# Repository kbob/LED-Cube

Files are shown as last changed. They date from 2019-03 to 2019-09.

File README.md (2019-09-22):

# LED Cube

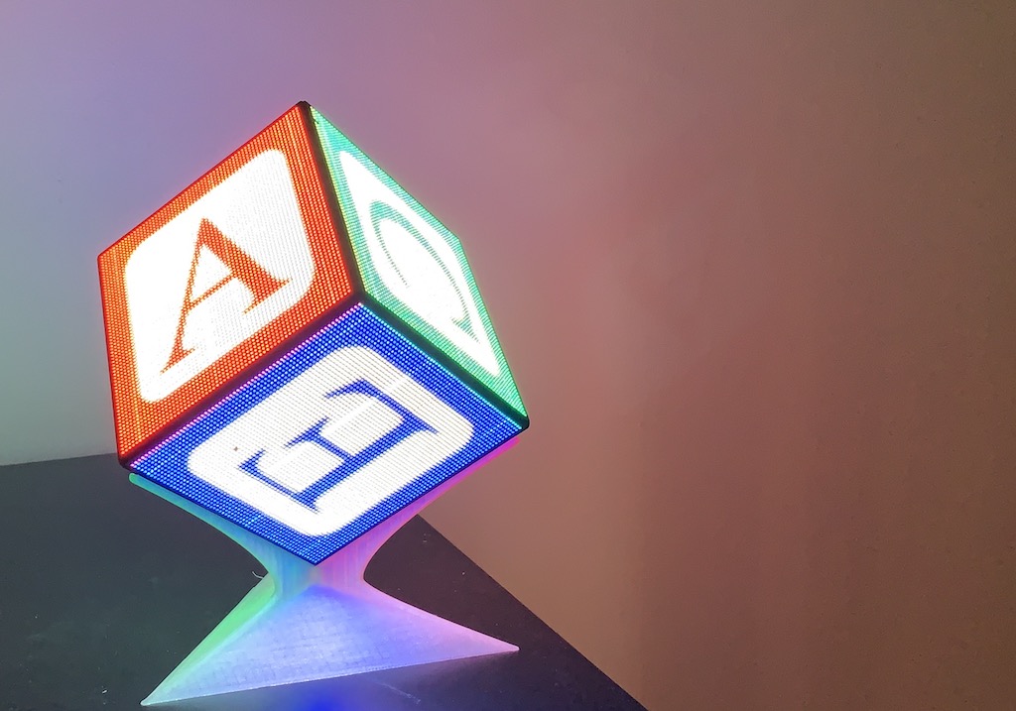
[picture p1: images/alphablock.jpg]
The cube on its stand.


A cube made of RGB LED panels.

I saw [Zaurak's and Polyfloyd's LED cubes](https://kbob.github.io/2019/08/23/led-cubes.html), and decided I wanted to make one too.  This one is smaller with denser LEDs.  (2mm pitch instead of 2.5mm)

# Overview

The cube's faces are six LED panels from Aliexpress.  Each panel has 64&times;64 RGB leds and is driven by the HUB75 protocol.

The chassis is a combination of 3D printed PLA, machine screws, and magnets.
The electronics can be installed and removed without tools.

The electronics consist of a Raspberry Pi connected via USB to an
[iCEBreaker FPGA](https://www.crowdsupply.com/1bitsquared/icebreaker-fpga)
dev board, HUB75 PMOD interface, and the panels.

Power is provided by an eight pack of 18650 batteries and a custom
power supply.  The power board also has an inertial measurement
unit (IMU), battery level monitoring, and soft power controls.

I also have two different display stands that prop the cube up on
one corner.  One stand disassembles for easy transport; the other, shown above,
is more stable and has a (bulky) carrying case.  All this is 3D printed.

# What's Here?

* **Mechanical/** CAD files, STL files, and parts lists.  The two
  display stands are here too.

* **Power Board/** KiCAD files and BOM for the custom power board.

* **Wiring/** Notes on the wiring harness.

* **Linux/** Notes on configuring Linux on the Raspberry Pi.

# What's Missing?

There are several different software options.  I outlined them in
[this 'blog post](https://kbob.github.io/2019-08-23/led-cubes.html).
None of them are in this repository.  I couldn't even begin
to write a comprehensive installation guide for them all.

The gateware is based on [tnt's excellent
ice40-playground](https://github.com/smunaut/ice40-playground).
But I have my own fork [here](https://github.com/kbob/ice40-playground).
My cube uses the `topic-cube` branch.  I haven't checked whether everything
in that branch has made it back upstream.

# What's Coming (I hope)?

## Raspberry Pi 4

My cube has a Raspberry Pi 3 Model A+.  (What a mouthful!)
Shortly after I built it, the Raspberry Pi foundation announced
the Raspberry Pi 4.  Its GPU is much better, and I really want to
get it into my cube.  But of course it's a different size;
I have to redesign part of the chassis to make it fit.

# Mesa OpenGL

I am using Broadcom's proprietary OpenGL.  I want to get the
open source Mesa GL running, but haven't figured out the magic
yet.  (It's complicated because I refuse to install an X11 server;
I only want offscreen rendering.)

# More LED Panels

**Update 2019-09-22:**  Good news!  1BitSquared now has [the correct
LED panels](https://1bitsquared.com/collections/embedded-hardware/products/led-panel)
in stock.  Get the ICN2037 variant.

The Aliexpress vendors do not ship a single version of the HUB75
panels.  Instead, you get whatever vendors happen to be available
surplus.  Each version has different driver chips, timing requirements,
mechanical layout, even power voltage requirements.  So today
the panels on the cube are irreplaceable.  If one dies, I'll
have no cube.

~~Esden is working on getting a reliable source for LED panels.
Follow him on twitter ([@esden](https://twitter.com/esden))
to stay up to date.~~

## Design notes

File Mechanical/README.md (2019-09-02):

# LED Cube Mechanicals

This directory holds the mechanical parts of the cube
and its accessories.  It is organized into subdirectories.

* **Cube/** The cube.

 

* **Interlocking Stand/** Display stand made of three
interlocking pieces.  Breaks down for easy transport.

 

* **Display Stand/** Single-piece display stand.  Sturdier
than the interlocking stand but bulkier.

 

* **Display Stand/Travel Case/** a travel case for the
single-piece display stand.

 

Each subdirectory should have a README, a BOM, some Fusion 360 files, some STL files, and a picture or two.

## Versions

Each Fusion 360 file has a version number appended.
Fusion 360 exports do not include version history,
so earlier versions are not available, in general.

Some Fusion 360 files have both a generation and
a version.  Sometimes I just gave up on a design and started over.
When I did, I added a generation number.  *e.g.*, `Pi Connector Cover 4 v3.f3d`.
That's version 3 of the 4th try to design a connector cover.

Each STL file has a version number appended.  That
corresponds to the Fusion 360 version where that
body was last changed.  So the STL versions will
generally be less than the F360 version.  Version
64 of the cube uses v35 of the lid, for example.

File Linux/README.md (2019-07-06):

# Linux Configuration

The Raspberry Pi inside the cube runs Linux.  There are
a few necessary steps to configure it.  This file is
a checklist of things to set up.

## Make Image.

Get a Raspbian-Lite image from
[raspberrypi.org](https://www.raspberrypi.org/downloads/).
Burn it to a Micro SD card.

## Set up soft power.

Before putting the card into the Raspberry Pi, append this to /boot/config.txt.

    # BEGIN kbob 2019-03-25 configure soft power GPIO
    dtoverlay=gpio-shutdown,gpio_pin=17,active_low=1,gpio_pull=up
    dtoverlay=gpio-poweroff,gpiopin=4,active_low=1,export=1
    # END kbob 2019-03-25

## Configure Wi-Fi

Before putting the card into the Raspberry Pi, create the file
`/boot/wpa_supplicant.conf`.

    country=us
    update_config=1
    ctrl_interface=/run/wpa_supplicant

    network={
      scan_ssid=1
      ssid="(your network SSID)"
      psk="(your network password)"
    }

Duplicate the `network={...}` stanza if you have several Wi-Fi networks.

## Enable ssh.

Before putting the card into the Raspberry Pi, create an empty file
`/boot/ssh`.

## Boot Raspberry Pi.

The Pi should boot and bring up Wi-Fi.  Use a network scanner to find
it and log in.

## Change the password.

Immediately run `sudo raspi-config` and change the default user's
login password.

## Run `raspi-config`

Use `sudo raspi-config` to change the hostname, locale and timezone and
enable I&sup2;C.  Also select the "legacy" GL driver.

GL driver is under Advanced Options.

## Expand swap space

Building the FPGA tools requires 4 GB of swap.  Edit
`/etc/dphys-swapfile` and set these.

    CONF_SWAPSIZE=4096
    CONF_MAXSWAP=4096

N.B., this is not a sane swap configuration.  But building the FPGA toolchain
on a Raspberry Pi is not a sane thing to do.

Reboot to enable the new swap space.

## Enable Bonjour ssh service.

Create `/etc/avahi/services/ssh.service`.

    $ sudo cp /usr/share/doc/avahi-daemon/ssh.service /etc/avahi/services/

## Update and install packages

    $ sudo apt-get update
    $ sudo apt-get dist-upgrade

These packages are needed for the FPGA tools.

    $ sudo apt-get install git mercurial build-essential bison clang cmake \
                           flex gawk graphviz xdot libboost-all-dev \
                           libeigen3-dev libffi-dev libftdi-dev libgmp3-dev \
                           libmpfr-dev libncurses5-dev libmpc-dev \
                           libreadline-dev zlib1g-dev pkg-config python \
                           python3 python3-dev tcl-dev autoconf gperf

## Summon the FPGA tools.

    $ git clone https://github.com/esden/summon-fpga-tools.git
    $ cd summon-fpga-tools
    $ ./summon-fpga-tools.sh CPUS=1 NEXTPNR_BUILD_GUI=off

This will run for several hours.  Good time to take a break.

# Apt History

Here is the raw history.  Some of these are probably not needed.

```text
history.log.1:Commandline: apt-get install raspi-config
history.log.1:Commandline: apt-get dist-upgrade
history.log.1:Commandline: apt-get install git
history.log.1:Commandline: apt-get install build-essential clang bison flex libreadline-dev gawk tcl-dev libffi-dev git mercurial graphviz xdot pkg-config python python3 libftdi-dev python3-dev libboost-all-dev cmake libeigen3-dev
history.log.1:Commandline: apt-get install autoconf
history.log.1:Commandline: apt-get install gperf
history.log.1:Commandline: apt-get install python3-pip
history.log.1:Commandline: apt-get install python3-ftdi1
history.log.1:Commandline: apt-get install emacs-nox
history.log.1:Commandline: apt-get install swig
history.log:Commandline: apt-get install python-virtualenv
history.log:Commandline: apt-get install mesa-utils
history.log:Commandline: apt-get install python-imaging
history.log:Commandline: apt-get purge mesa-utils
history.log:Commandline: apt-get install golang
history.log:Commandline: apt-get install libgl1-mesa-dev
history.log:Commandline: apt-get install libegl1-mesa-dev
history.log:Commandline: apt-get install ffmpeg
history.log:Commandline: apt-get install libgbm-dev
history.log:Commandline: apt-get install ltrace
history.log:Commandline: apt-get install stress
history.log:Commandline: apt-get install i2c-tools
history.log:Commandline: apt-get install libgles2-mesa-dev
history.log.1:Commandline: apt-get install python3-pygments
history.log.1:Commandline: apt-get install python-pygments
history.log.1:Commandline: apt-get install tig
history.log.1:Commandline: apt-get dist-upgrade
history.log.1:Commandline: apt-get install apt-rdepends
history.log.1:Commandline: apt autoremove
history.log.1:Commandline: apt-get install git libeigen3-dev cmake wiringpi libboost-all-dev libasound2-dev libprotobuf-dev protobuf-compiler
history.log:Commandline: apt-get install mesa-utils-extra
history.log:Commandline: apt-get install avahi-utils
history.log:Commandline: apt install vim
history.log:Commandline: apt-get install libegl1-mesa-drivers
history.log:Commandline: apt-get install netpbm
history.log:Commandline: apt-get install libnetpbm10-dev
history.log:Commandline: apt-get install valgrind
history.log:Commandline: apt-get install python3-pil
history.log:Commandline: apt-get install python3-numpy
```

(more to come...)

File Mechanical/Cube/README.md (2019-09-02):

# The Cube - Mechanical

This directory contains the CAD files (Fusion 360) and
STL files for the cube's 3D printed parts.  The BOM
lists those and  the other misc. parts needed to build
a cube.

There are no assembly instructions, sorry.

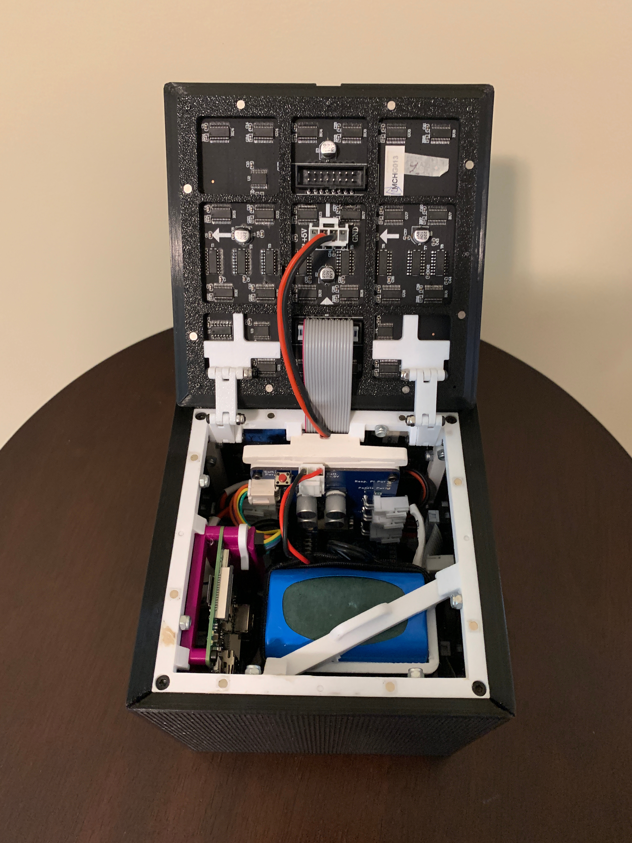
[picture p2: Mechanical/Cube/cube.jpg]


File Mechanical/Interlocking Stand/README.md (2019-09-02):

# Interlocking Display Stand

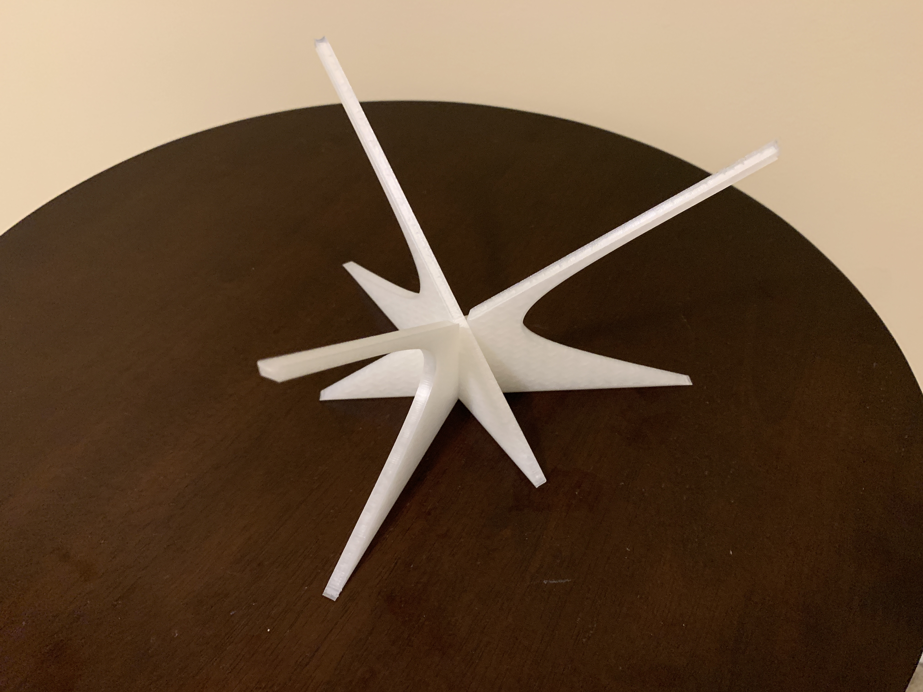
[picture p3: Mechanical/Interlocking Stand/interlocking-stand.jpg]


The interlocking display stand is 3D printed in three pieces.  They slide together to form the stand, and they
slide apart to lie flat for transport or storage.

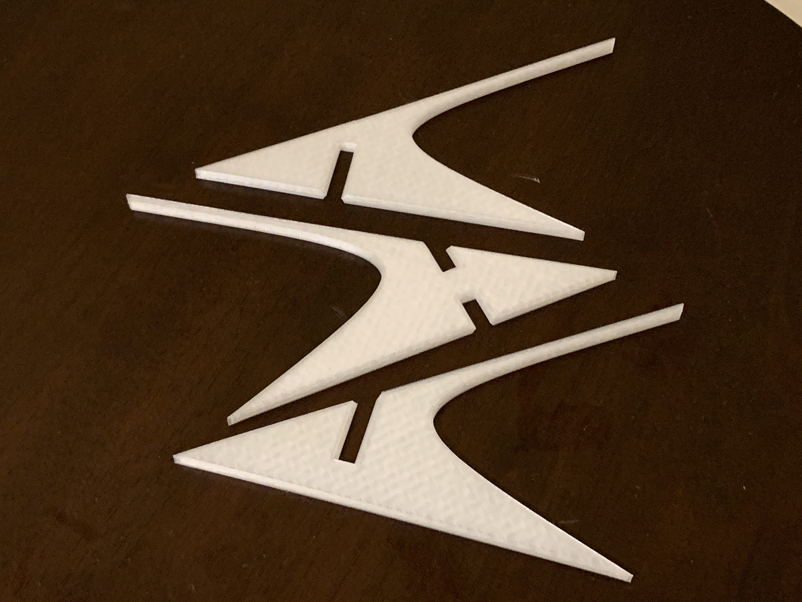
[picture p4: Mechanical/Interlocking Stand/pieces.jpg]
Pieces


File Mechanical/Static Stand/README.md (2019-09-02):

# Static Display Stand

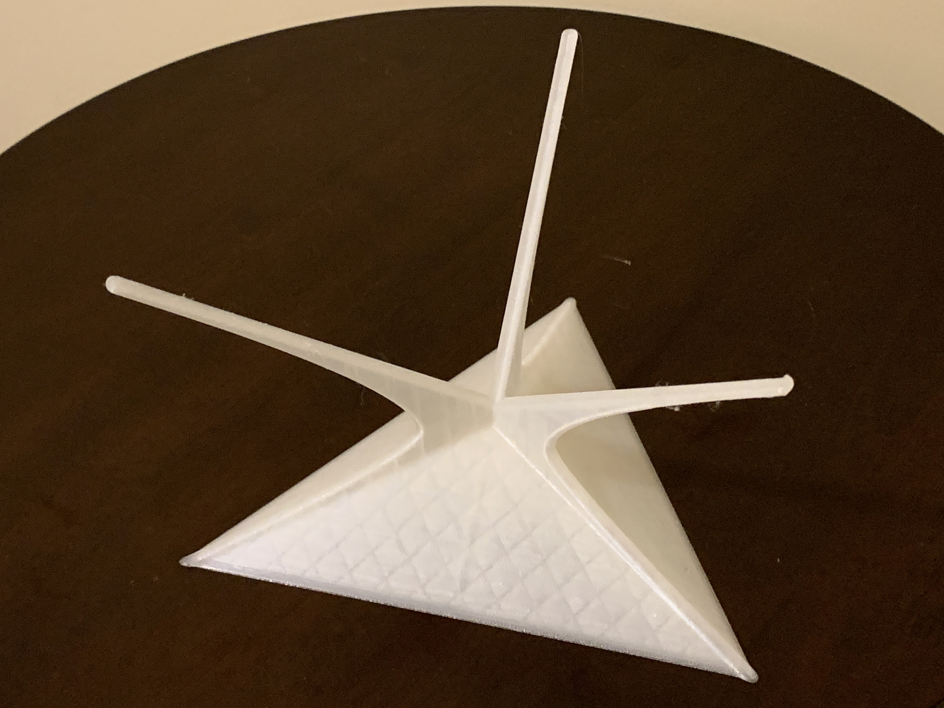
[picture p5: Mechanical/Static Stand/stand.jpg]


There is also a travel case in the `Travel Case/`
subdirectory.

The stand has a hole in the bottom that fits over
a short phonograph spindle.

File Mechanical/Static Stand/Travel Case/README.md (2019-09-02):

# Stand Travel Case

The travel case is 3D printed, held closed with rubber bands.
The stand is held in place by three plastic clips.

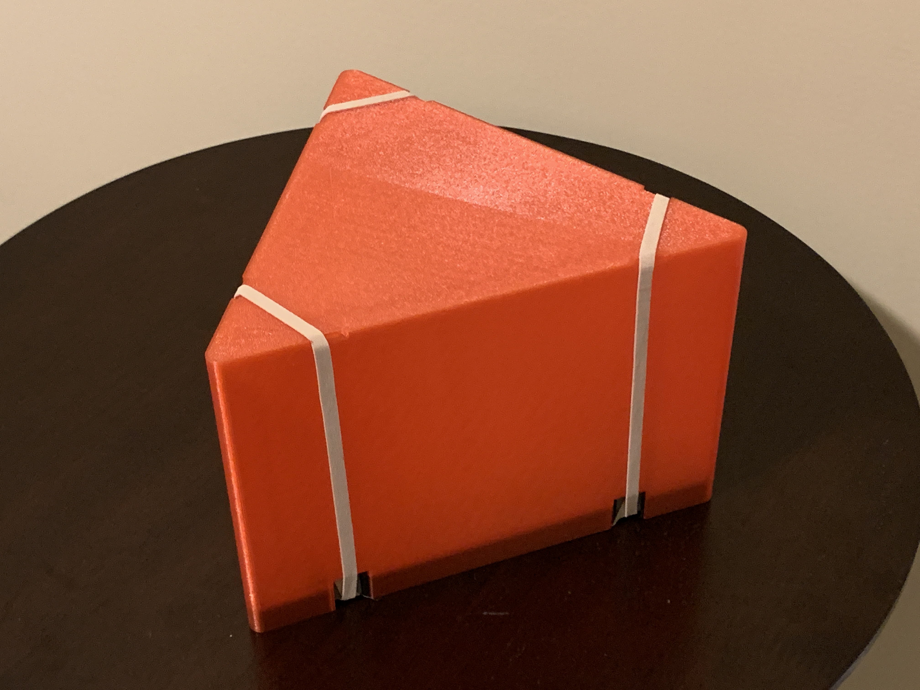
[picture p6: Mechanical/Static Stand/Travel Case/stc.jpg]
travel case


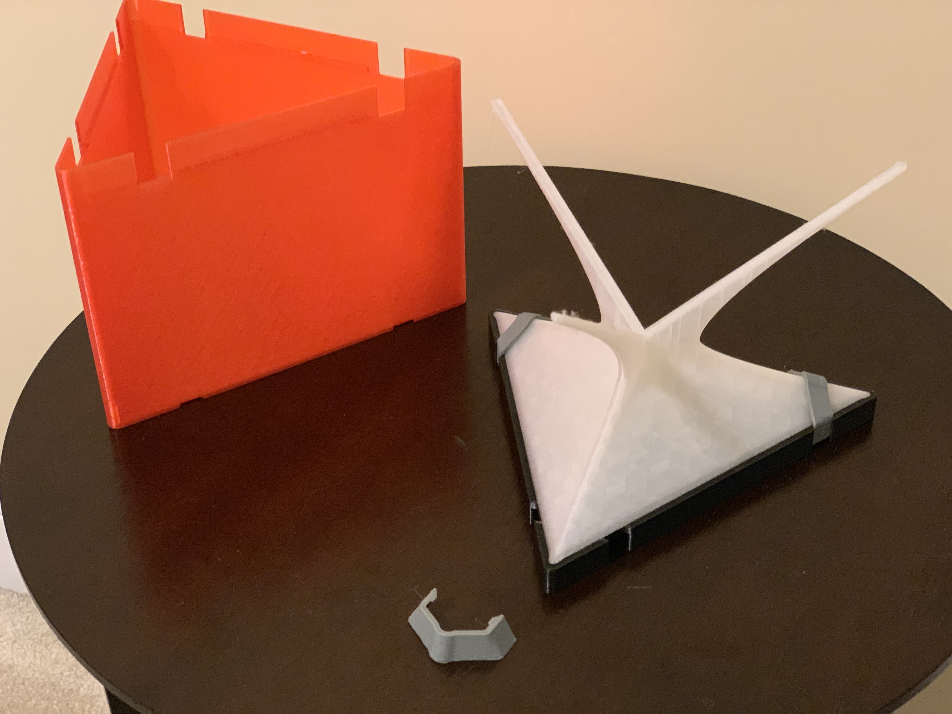
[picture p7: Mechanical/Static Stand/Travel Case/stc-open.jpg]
travel case open


It can optionally use another set of rubber bands for
redundant retention.

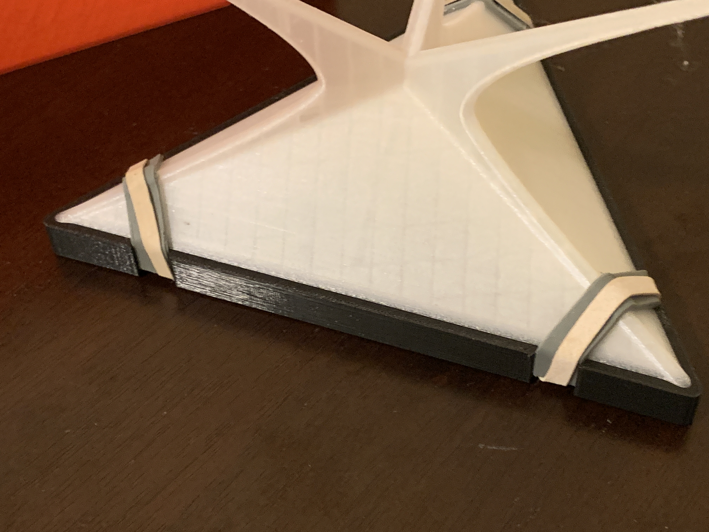
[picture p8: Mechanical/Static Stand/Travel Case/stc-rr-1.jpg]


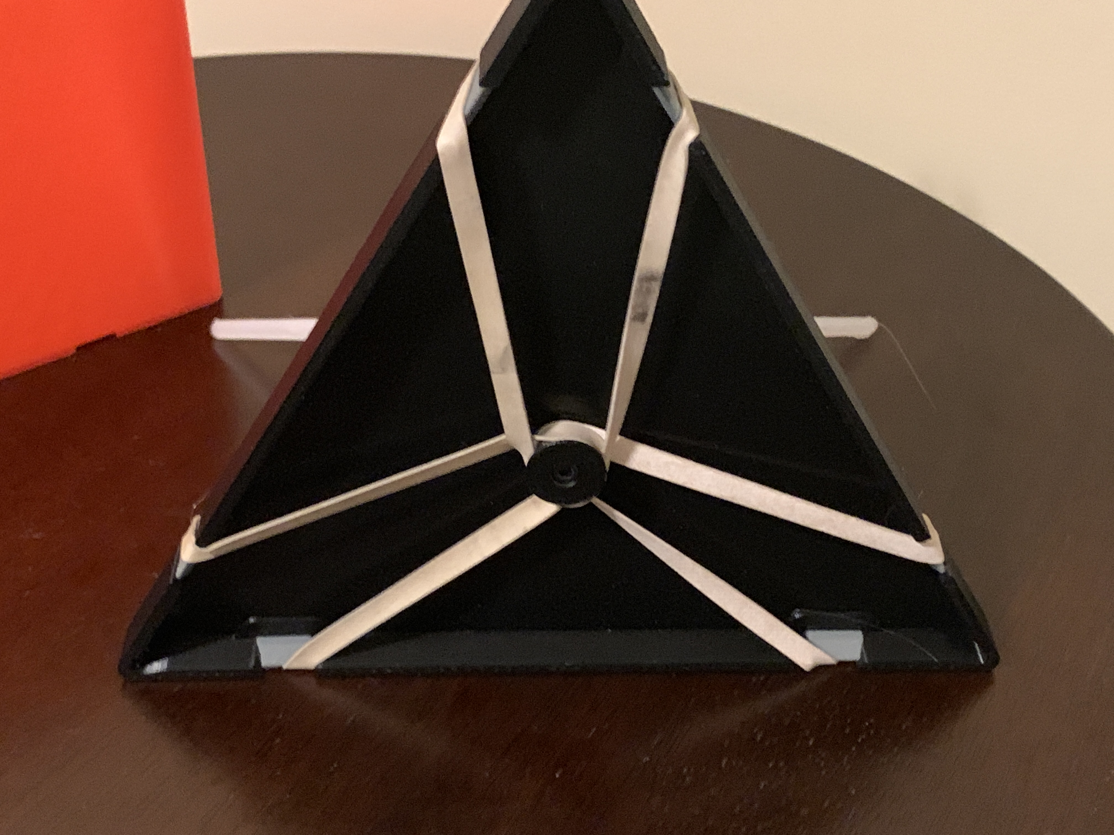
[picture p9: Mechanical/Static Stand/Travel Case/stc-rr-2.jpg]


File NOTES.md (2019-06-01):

# Raspberry Pi

## Configuration for soft power switch

In `/boot/config.txt`:
    # BEGIN kbob 2019-03-25 configure soft power GPIO
    dtoverlay=gpio-shutdown,gpio_pin=17,active_low=1,gpio_pull=up
    dtoverlay=gpio-poweroff,gpiopin=4,active_low=1,export=1
    # END kbob 2019-03-25

Some of those parameters are probably not needed.

# Power Board

## Power Board v0.3

### Capacitor Substitutions

Some of the caps I specified are not available.

Specifically, Digikey is out of these two.

    445-8047-1-ND     47uF 25V 1206
    490-1517-2-ND   0.22uF 50V 0603

And I incorrectly specified some 15V caps for components that are
expected to see 17V.

And Digikey does not carry NIC caps.

And it has been suggested that I use electrolytic caps instead
of some of these.

### Calculate LMZ14203 Parameters

#### Input Voltage

Nominal cell voltage is 3.7V.  Min is 3.3V; max is 4.2V.

Assume 4 cells.

```python
>>> vv = 3.3, 3.7, 4.2
>>> [4 * v for v in vv]
[13.2, 14.8, 16.8]
```

So nominal battery voltage is 14.8V, min and max are 13.2 and 16.8V.

#### Enable Divider

    Rent / Renb = (Vin_uvlo / 1.18V) - 1
    Rent / Renb + 1 = Vin_uvlo / 1.18V
    1.18V * (Rent / Renb + 1) = Vin_uvlo

    1.18V * (68K / 6.8K + 1) = 12.98V

So it will shut off when battery voltage drops below 12.98V.

#### FB voltage divider

Use R<sub>FBT</sub> = 5.90&ohm; and R<sub>FBB</sub> = 1.07&ohm;.

V<sub>0</sub> = 0.8V * (1 + R<sub>FBT</sub> / R<sub>FBB</sub>)
<br>
V<sub>0</sub> = 0.8V * (1 + 5.90 / 1.07)
<br>
V<sub>0</sub> = 5.21V

That's a healthy 5V. (-:

#### R<sub>ON</sub> Value

(See datasheet section 8.2.2.2.7.)

Minimum on time is 150ns.

R<sub>ON</sub> >= V<sub>IN(MAX)</sub> \* 150ns / (1.3 \* 10^-10)

R<sub>ON</sub> >= 16.8 * 150e-9 / 1.3e-10
       = 19384

T<sub>ON</sub> = (1.3 \* 10^-10 \* R<sub>ON</sub>) / V<sub>IN</sub>

WEBENCH uses 110K for R<sub>ON</sub>.  That gives T<sub>ON</sub> = 966nsec.
Is that good?  Is that bad?

## Calculate TPS53819A Parameters

All parameters are from WEBENCH.

## Power Board v0.2

### Polyfuses

    Bourns MF-MSMF250/16X-2
    as used on Raspberry Pi 3 Model B+

    LittelFuse 30R400UMR

    Better: LittelFuse NANOSMD400LR-C-2
    12V, 4A, 1206 SMT

### Capacitors

    Panasonic EEU-FC1C182S
    1800µF 16V 3000hours low ESR
    George I. recommended this one.

    Panasonic also makes some slightly shorter SMD caps.

    Panasonic EEU-FS1C511
    510uF, 16V, 6000 hours
    13mm high by 8mm diameter

    Digikey filtered list
    https://www.digikey.com/short/p347pv

### Connectors

   <!-- Solderable hole for power in
   2.54mm female socket for Raspberry Pi -->

   Molex SL connector for Raspberry Pi.
   070553-30001 receptacle      (right-angle, through hole, 2pos)
   50-57-9402   connector       (2pos, crimp)
   16-02-0103   socket contacts (22-24AWG, gold)
   mini-PV connector for Pi
   pins for mini-PV

  JST B2PS-VH for panel outputs.
  JST VHR-2N for cables
  JSR VHR-4N for LED panel end
  Plus crimp connectors.
  JST SVH-21T-P1.1

## Digi-Key order

    QTY DK-PART                 MANUFACTURER    MFR PART

     25 HHKC16H-ND              Assmann WSW     AWP 16-7240-T
     30 F9967CT-ND              LittelFuse      NANOSMD400LR-C-2
     10 MF-MSMF250/16X-2CT-ND   Bourns          MF-MSMF250/16X
     30 P122389-ND              Panasonic       EEU-FS1C511
     30 455-1648-ND             JST             B2PS-VH(LF)(SN)
     30 455-1183-ND             JST             VHR-2N
     30 455-1185-ND             JST             VHR-4N
    250 455-1133-1-ND           JST             SVH-21T-P1.1

    XXX need horizontal sockets.  Five line items(!)

      6 WM4900-ND               Molex           07055-30001
     10 WM2900-ND               Molex           50-57-9402
     25 WM2512-ND               Molex           16-02-0103
     10 609-2380-ND             Amphenol ICC    69176-006LF
     50 609-4518-ND             Amphenol ICC    47745-001LF

# References

## These pages were useful.

http://tech.mattmillman.com/info/crimpconnectors/

http://www.mosaic-industries.com/embedded-systems/microcontroller-projects/raspberry-pi/on-off-power-controller

http://www.mosaic-industries.com/embedded-systems/microcontroller-projects/electronic-circuits/push-button-switch-turn-on/latching-toggle-power-switch

## George's big list of capacitor references

### GeorgeIoak 2019-03-31T17:29:05.284Z

Here's some good reading material I've saved links to over the years. I use Evernote to store web pages and info so here's some of what I've tagged. I don't mean to flood you with information but at the time I read these I felt they were good enough to save so I'm just sharing. Probably should create some web page and organize them but oh well. Would be nice to pull relevant info out of each and make 1 general reference page as I'm sure there is a ton of repeat information here.

[muRata](https://www.murata.com/~/media/webrenewal/support/library/catalog/products/emc/emifil/c39e.ashx)
<br>
[Analog Devices](https://www.analog.com/en/analog-dialogue/articles/ferrite-beads-demystified.html)
<br>
[TI](http://www.ti.com/lit/an/slva773/slva773.pdf)
<br>
[AVX](http://www.avx.com/docs/techinfo/SMPSCapacitors/Output_Filters.pdf)
<br>
[TI Blog](https://training.ti.com/sites/default/files/docs/measuring_output_noise.pdf)
<br>
[TI App Note](http://www.ti.com/lit/an/snva054c/snva054c.pdf)
<br>
[TI Analog Journal](http://www.ti.com/lit/an/slyt639/slyt639.pdf)
<br>
[TI Analog Engineer's Pocket Reference](https://www.dropbox.com/s/16wxvkue5hagz2q/Analog%20Engineer%E2%80%99s%20Pocket%20Reference.pdf?dl=0)
<br>
[AVX TAP/TEP Technical Summary and Application Guidelines](http://www.avx.com/docs/techinfo/TechSumAppGuide.pdf)
<br>
[Chris Reynolds - Parasitics & Capacitor Selection](https://www.planetanalog.com/author.asp?section_id=3245&doc_id=562601)
<br>
[TI Controlling Output Ripple](http://www.ti.com/lit/an/snva166a/snva166a.pdf)
<br>
[Maxim](https://www.maximintegrated.com/en/app-notes/index.mvp/id/5527),

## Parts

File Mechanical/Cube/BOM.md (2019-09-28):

# LED Cube - BOM

## 3D Printed Parts

Qty | Desc.                | Notes
---:|----------------------|-------
  5 | Frame                | Note P.1
  1 | Lid
  1 | Left Hinge Pivot
  1 | Right Hinge Pivot
  2 | Upper Link
  2 | Lower Link
  1 | Skeleton Bottom
  1 | Skeleton Top
  1 | Skeleton Left Rear
  1 | Skeleton Right Rear
  1 | Skeleton Left Front
  1 | Skeleton Right Front
  1 | Bottom Shelf
  1 | Rear Partition
  1 | Pi Carrier
  1 | Pi Connector Cover
  1 | Pi Connector Clip
  1 | Battery Carrier

##### Note P.1

The CAD file includes an alternate Frame called Left Frame.
It has clearance for a PCB attached to the HUB75 in connector.  I decided not to use that PCB, but removing
it from the CAD file would be a bother.

## Electronics

Qty | Desc.                              | Source             | Notes
----|------------------------------------|--------------------|----------
  1 | 4s2p 18650 Battery Pack w/ Charger | [AliExpress][ae1]  | Note E.1
  1 | Power Board                        | this repository
  1 | Raspberry Pi                       | any                | Note E.2
  1 | MicroSD card, 16GB or more         | any
  1 | iCEBreaker FPGA                    | [1BitSquared][1b1]
  1 | PMOD LED Panel Driver              | [1BitSquared][1b2]
  6 | P2 LED Panel                       | [1BitSquared][1b3] | Note E.3

[ae1]: https://www.aliexpress.com/item/32913021851.html
[1b1]: https://www.crowdsupply.com/1bitsquared/icebreaker-fpga
[1b2]: https://1bitsquared.com/products/pmod-led-panel-driver
[1b3]: https://1bitsquared.com/collections/embedded-hardware/products/led-panel

##### Note E.1

This battery's charger comes with a European power plug.  If your
country uses a different power plug, you'll need an adapter.  The
charger works with 120V or 240V.

##### Note E.2

Raspberry Pi 3 Model A+ is currently tested.  Hope to
use Raspberry Pi 4 in the future, but it doesn't fit
the current cube.

##### Note E.3

~~I have no reliable source for LED panels that fit these frames.~~
1BitSquared is now carrying the correct panel.  Be sure to get the
ICN2037 version.
See README in this repository's top directory for more info.

## Wires

See Wiring directory in this repository.

## Hardware

Qty | Desc.                                     | Source
---:|-------------------------------------------|--------
  8 | block magnet, 3/16"&times;3/16"&times;1/16" | [K&J Magnetics B331][kj1]
  8 | block magnet, 3/16"&times;3/16"&times;3/16" | [K&J Magnetics B333][kj2]
  4 | M2.5&times;20mm button head screw         | [McMaster-Carr 91239A764][mc1]
  2 | M2.5&times;16mm button head screw         | [McMaster-Carr 91239A762][mc2]
  6 | M2.5 nylon hex locknut                    | [McMaster-Carr 93625A102][mc3]
 24 | M1&times;4mm Phillips head screw          | [AliExpress][ae2]
 38 | M3&times;12mm hex head screw              | [McMaster-Carr 91280A108][mc4]
 38 | M3 nylon hex locknut                      | [McMaster-Carr 90576A102][mc5]
  8 | M3&times;16mm socket head screw           | [McMaster-Carr 91290A120][mc6]
  4 | M3&times;6 socket head screw              | [McMaster-Carr 91290A111][mc7]
  4 | M2.5&times;8 socket head screw            | [McMaster-Carr 91290A102][mc8]
  4 | M2.5&times;10 socket head screw           | [McMaster-Carr 91290A103][mc9]

[kj1]: https://www.kjmagnetics.com/proddetail.asp?prod=B331
[kj2]: https://www.kjmagnetics.com/proddetail.asp?prod=B333

[ae2]: https://www.aliexpress.com/item/1000008061219.html

[mc1]: https://www.mcmaster.com/91239A764
[mc2]: https://www.mcmaster.com/91239A762
[mc3]: https://www.mcmaster.com/93625A102
[mc4]: https://www.mcmaster.com/91280A108
[mc5]: https://www.mcmaster.com/90576A102
[mc6]: https://www.mcmaster.com/91290A120
[mc7]: https://www.mcmaster.com/91290A111
[mc8]: https://www.mcmaster.com/91290A102
[mc9]: https://www.mcmaster.com/91290A103

## Misc. Parts

Qty | Desc.                    | Source
----|--------------------------|--------------
  1 | 3/4" Velcro strap, 285mm | [Amazon][m1]

[m1]: https://www.amazon.com/VELCRO-Brand-ONE-WRAP-Double-Sided-Multi-Purpose/dp/B000LNSSVY

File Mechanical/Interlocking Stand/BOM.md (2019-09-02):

# Interlocking Display Stand - BOM

## 3D Printed Parts

Qty | Desc.
---:|------------------
  1 | Portable Stand A
  2 | Portable Stand B
  3 | Portable Stand C

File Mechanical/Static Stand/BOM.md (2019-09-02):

# Static Stand - BOM

The static stand's BOM is pretty simple.  It's
just one piece.

Qty | Desc.
---:|----------------------
 1  | Static Stand w: Hole

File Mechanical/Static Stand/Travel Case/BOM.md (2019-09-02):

# Stand Travel Case - BOM

## Basic Travel Case

### 3D Printed Parts

Qty | Desc.
---:|----------
  1 | STC Base
  1 | STC Lid
  3 | STC Clip

### Misc. Parts

Qty | Desc.           | Source
---:|-----------------|--------
  3 | #64 rubber band | [Staples #808659][rb64]

  [rb64]: https://www.staples.com/Staples-Economy-Rubber-Bands-Size-64-1-lb/product_808659

## Optional Redundant Retention

### Misc. Parts

Qty | Desc.           | Source
---:|-----------------|--------
  1 | M3x8mm socket head screw | [McMaster-Carr 91290A111][m1]
  3 | #64 rubber band | [Staples #808659][rb64]

[m1]: https://www.mcmaster.com/91290a111

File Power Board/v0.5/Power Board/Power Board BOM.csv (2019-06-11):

Reference | Quantity | Value | Footprint | Datasheet | Digikey No. | Manufacturer | Part No. | Package
C10 | 1 | 100µF | Capacitor_SMD:C_1210_3225Metric | ~ | 587-1965-1-ND | Taiyo Yuden | LMK325BJ107MM-T
C16 | 1 | 1nF | Capacitor_SMD:C_0603_1608Metric | ~ | 399-1083-1-ND | Kemet | C0603C102J5RACTU
C17 C13 C31 | 3 | 10µF | Capacitor_SMD:C_1206_3216Metric | ~ | 490-10748-1-ND | Murata | GRM21BR61E106MA73L
C19 C20 C21 C22 | 4 | 47µF | Power_Board:CP_OSCON_Poly_F12 | ~ | PCE5080CT-ND | Panasonic | 35SVPD47M
C2 C15 | 2 | 100nF | Capacitor_SMD:C_0805_2012Metric | ~ | 445-5827-1-ND | TDK | CGA4J2X7R2A104K125AA
C23 C24 C25 C26 | 4 | 47µF | Capacitor_SMD:C_1210_3225Metric | ~ | 490-10531-1-ND | Murata | GRM32EC81C476KE15L
C28 C27 C30 | 3 | 100nF | Capacitor_SMD:C_0603_1608Metric | ~ | - | Murata | GRM188R71C104KA01D
C3 | 1 | 100µF | Capacitor_SMD:CP_Elec_8x10 | https://datasheet.octopart.com/EDK107M050A9MAA-Kemet-datasheet-13271990.pdf | 399-6672-1-ND | Kemet | EDK107M050A9MAA
C5 C4 | 2 | 10µF | Capacitor_SMD:C_0805_2012Metric | ~ | 490-10748-1-ND | Murata | GRM21BR61E106MA73L
C6 C9 C1 C14 C11 | 5 | 1µF | Capacitor_SMD:C_0805_2012Metric | ~ | 587-1438-1-ND | Taiyo Yuden | GMK212B7105KG-T
C7 C29 | 2 | 10nF | Capacitor_SMD:C_0603_1608Metric | ~ | - | Murata | GRM188R71H103KA01D | 0603
C8 | 1 | 22nF | Capacitor_SMD:C_0603_1608Metric | ~ | 732-8009-1-ND | Wurth | 885012206091
D1 | 1 | LED, green | LED_SMD:LED_0603_1608Metric | ~ | - | Osram | LG Q971-KN-1
D2 | 1 | LED, blue | LED_SMD:LED_0603_1608Metric | ~ | - | Osram | LB Q39G-L2N2-35-1
D3 | 1 | BAT54C | Package_TO_SOT_SMD:SOT-23 | https://www.diodes.com/_files/datasheets/ds11005.pdf | BAT54CCT-ND | Diodes Inc. | BAT54CTA
F6 F5 F4 F3 F2 F1 | 6 | Fuse | Power_Board:Fuse_1206_3216Metric | ~ | F9967CT-ND | Littelfuse | NANOSMD400LR-C-2
H1 H2 H3 H4 | 4 | MountingHole | MountingHole:MountingHole_2.7mm_M2.5 | ~ | - | - | -
J1 | 1 | Battery In | Power_Board:JST_VH_B3PS-VH_1x03_P3.96mm_Horizontal |  | 455-1649-ND | JST | B3PS-VH(LF)(SN)
J7 J6 J5 J4 J3 J2 | 6 | JST B2PS-VH | Power_Board:JST_VH_B2PS-VH_1x02_P3.96mm_Horizontal | ~ | 455-1648-ND | JST | B2PS-VH(LF)(SN)
J9 | 1 | Raspberry Pi | Connector_JST:JST_PUD_S10B-PUDSS-1_2x05_P2.00mm_Horizontal | ~ | 455-2486-ND | JST | S10B-PUDSS-1(LF)(SN)
L1 L2 L3 L4 L5 L6 L7 | 7 | 60R | Inductor_SMD:L_1206_3216Metric | https://ds.yuden.co.jp/TYCOMPAS/ut/detail?pn=FBMJ3216HM600-T%20%20&u=M | 587-1770-1-ND | Taiyo Yuden | FBMJ3216HM600-T
L8 | 1 | 1.3µH | Power_Board:Coilcraft_XAL1580 | ~ | Mouser | Coilcraft | XAL1580-132MEB
Q1 | 1 | SI5504BDC | Power_Board:1206-8_or_SO-8 | http://www.vishay.com/docs/74483/si5504bdc.pdf | SI5504BDC-T1-GE3CT-ND | Vishay | SI5504BDC-T1-GE3
R10 | 1 | 120K | Resistor_SMD:R_0603_1608Metric | ~ | - | Yageo | RC0603JR-07120K | 0603
R11 | 1 | 5.90K 1% | Resistor_SMD:R_0603_1608Metric | ~ | P5.90KHCT-ND | Panasonic | ERJ-3EKF5901V | 0603
R12 | 1 | 1.07K 1% | Resistor_SMD:R_0603_1608Metric | ~ | P1.07KHCT-ND | Panasonic | ERJ-3EKF1071V | 0603
R13 | 1 | 38.3K | Resistor_SMD:R_0603_1608Metric | ~ | RMCF0603FT38K3CT-ND | Stackpole | RMCF0603FT38K3
R14 | 1 | 294K | Resistor_SMD:R_0402_1005Metric | ~ | 541-294KLCT-ND | Vishay-Dale | CRCW0402294KFKED
R15 | 1 | 976 | Resistor_SMD:R_0402_1005Metric | ~ | 541-976LCT-ND | VIshay-Dale | CRCW0402976RFKED
R17 R19 | 2 | 1 | Resistor_SMD:R_0805_2012Metric | ~ | 541-1.00CCCT-ND | Vishay-Dale | CRCW08051R00FKEA
R18 | 1 | 4.7 | Resistor_SMD:R_0805_2012Metric | ~ | P4.7DCT-ND | Panasonic | ERJ-6RQF4R7V
R2 R1 | 2 | 680 | Resistor_SMD:R_0603_1608Metric_Pad1.05x0.95mm_HandSolder | ~ | - | Yageo | RC0603JR-07680R
R20 R22 | 2 | 10K 1% | Resistor_SMD:R_0603_1608Metric | ~ | RNCP0603FTD10K0CT-ND | Stackpole | RNCP0603FTD10K0
R21 R23 | 2 | 1.78K 1% | Resistor_SMD:R_0603_1608Metric | ~ | 311-17.8KHRCT-ND | Yageo | RC0603FR-0717K8L
R24 R7 R4 R16 | 4 | 100K | Resistor_SMD:R_0603_1608Metric | ~ | - | Yageo | RC0603JR-07100K
R3 | 1 | 10K | Resistor_SMD:R_0603_1608Metric | ~ | - | Yageo | RC0603JR-0710K
R5 | 1 | 330K | Resistor_SMD:R_0603_1608Metric | ~ | - | Yageo | RC0603JR-07330K
R6 | 1 | 1K | Resistor_SMD:R_0603_1608Metric | ~ | - | Yageo | RC0603JR-071K
R8 | 1 | 68K | Resistor_SMD:R_0603_1608Metric | ~ | - | Yageo | RC0603JR-0768K | 0603
R9 | 1 | 6.8K | Resistor_SMD:R_0603_1608Metric | ~ | - | Yageo | RC0603JR-076K8 | 0603
SW1 | 1 | SW_Push | Power_Board:PTS645-Vx-39-2 | ~ | CKN10053-ND | C&K | PTS645VK39-2 LFS
U1 | 1 | LMZ14203 | Power_Board:TO-PMOD_7 |  | LMZ14203TZX-ADJ/NOPBCT-ND | TI | LMZ14203TZX-ADJ/NOPB | TO-PMOD 7
U2 | 1 | TPS53819A | Power_Board:VQFN-16-1EP_3x3mm_P0.5mm_EP1.68x1.68mm_ThermalVias |  | 296-35480-1-ND | TI | TPS53819ARGTR
U3 | 1 | CSD86360Q5D | Power_Board:Q5D |  | 296-35026-1-ND | TI | CSD86360Q5D
U4 | 1 | MPU-9250 | Sensor_Motion:InvenSense_QFN-24_3x3mm_P0.4mm | https://store.invensense.com/datasheets/invensense/MPU9250REV1.0.pdf | 1428-1019-1-ND | InvenSense | MPU-9250
U5 | 1 | ADS1000 | Package_TO_SOT_SMD:SOT-23-6 | http://www.ti.com/lit/ds/symlink/ads1000.pdf | 296-38847-1-ND | TI | ADS1000A0IDBVR

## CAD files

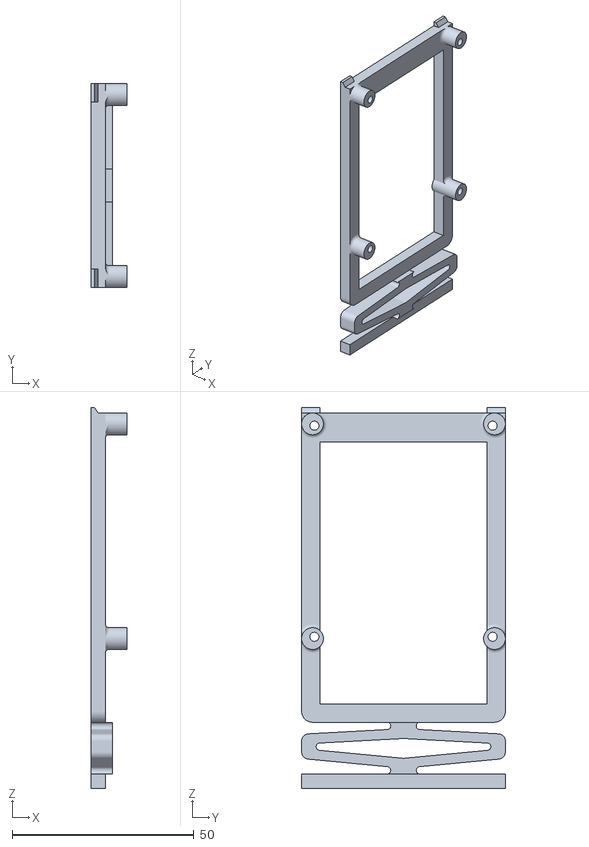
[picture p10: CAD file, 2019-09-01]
Mechanical/Cube/Pi Carrier v43.stl
10.0 x 56.0 x 104.7

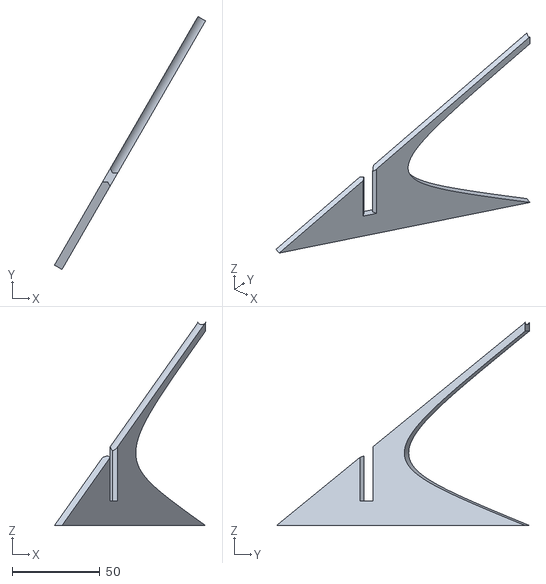
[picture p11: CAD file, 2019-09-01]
Mechanical/Interlocking Stand/Portable Stand A.stl
86.2 x 144.3 x 115.8

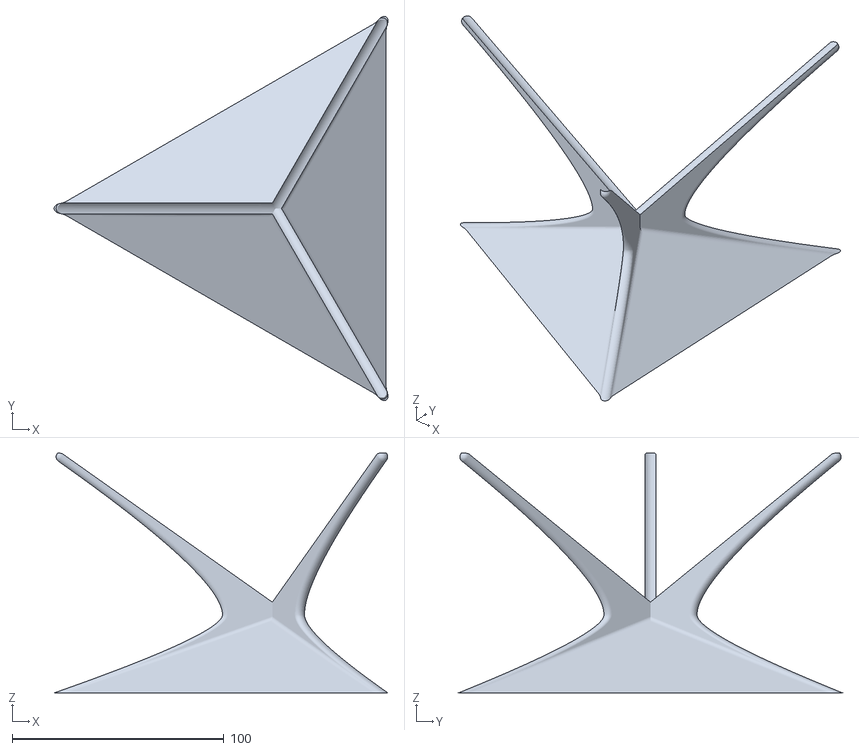
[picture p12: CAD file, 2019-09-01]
Mechanical/Static Stand/Static Stand w: Hole.stl
157.7 x 181.4 x 113.3

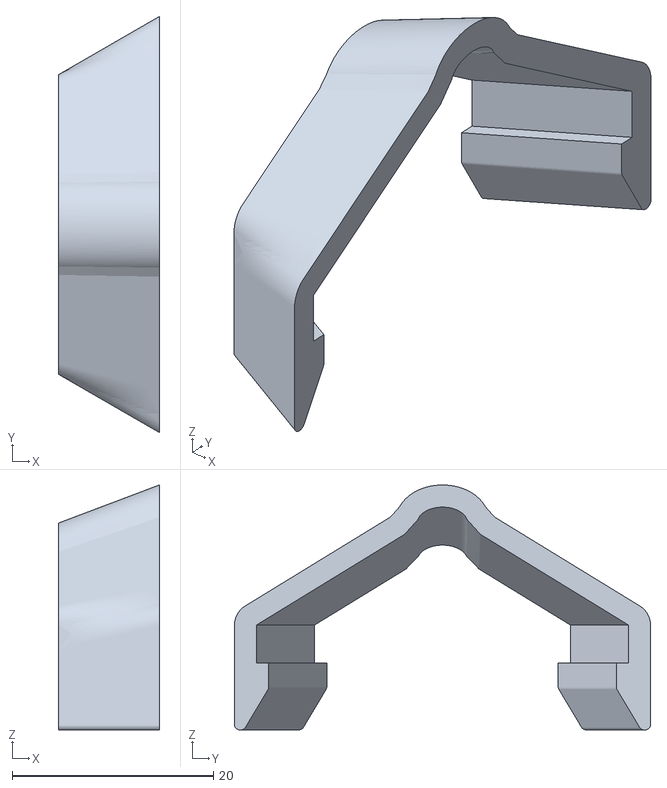
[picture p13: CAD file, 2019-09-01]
Mechanical/Static Stand/Travel Case/STC Clip v9.stl
10.0 x 41.4 x 24.4

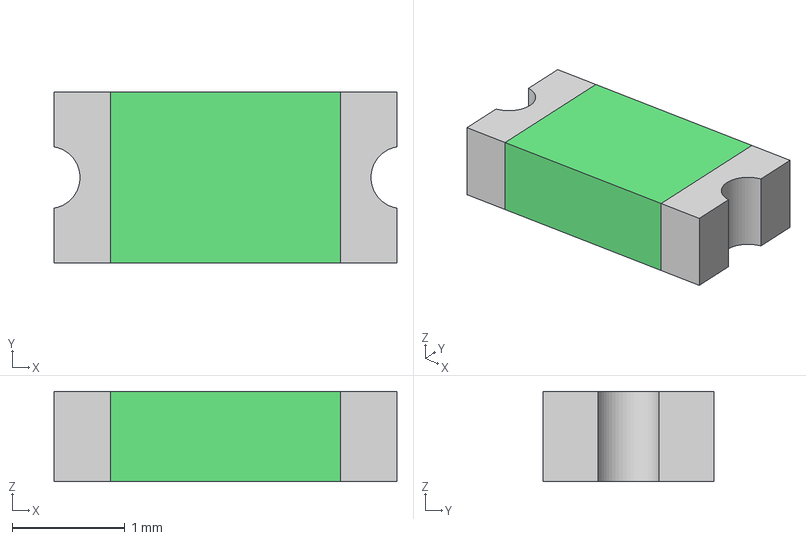
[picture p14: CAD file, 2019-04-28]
Power Board/v0.5/Power Board Models/LittelFuse_nanoSMD400LR-C.step
3.05 x 1.52 x 0.8 mm

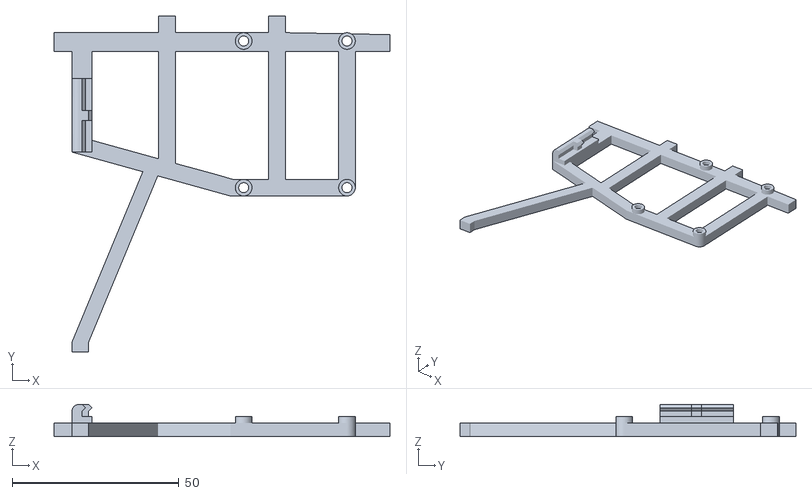
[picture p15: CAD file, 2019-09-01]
Mechanical/Cube/Bottom Shelf v54.stl
100.8 x 100.8 x 9.60

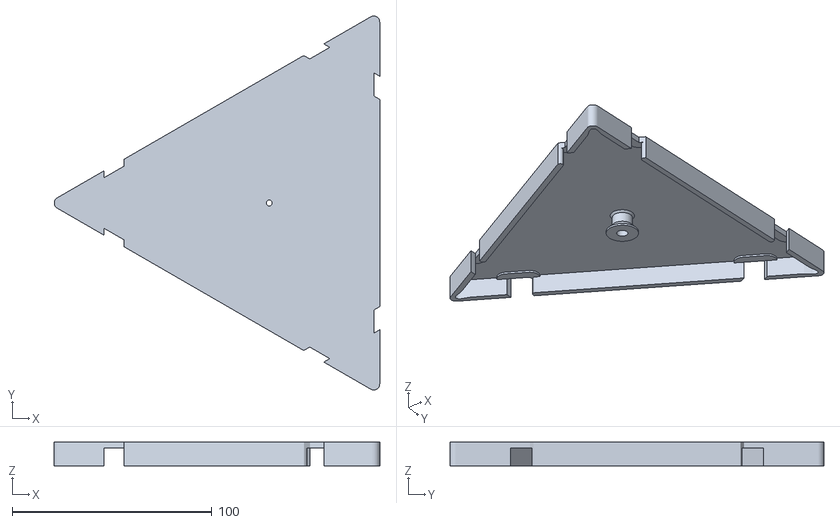
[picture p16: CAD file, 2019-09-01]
Mechanical/Static Stand/Travel Case/STC Base v4.stl
162.8 x 187.0 x 12.0

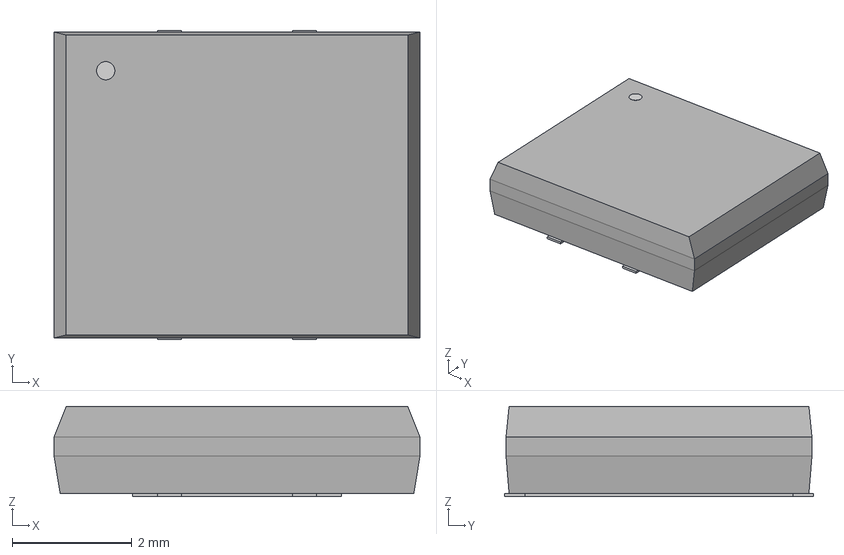
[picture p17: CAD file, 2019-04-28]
Power Board/v0.5/Power Board Models/DQY8_3P2X4P3 v1.step
6.10 x 5.15 x 1.50 mm

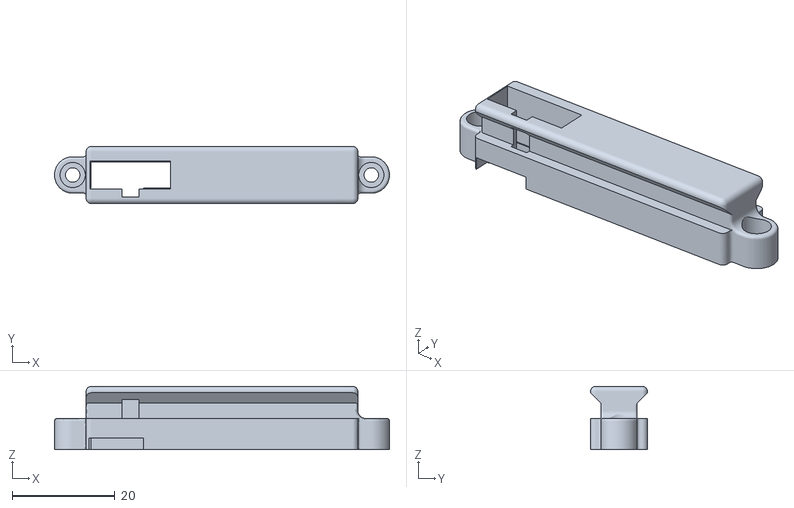
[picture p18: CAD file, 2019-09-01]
Mechanical/Cube/Pi Connector Cover 4 v4.stl
65.1 x 11.1 x 12.3

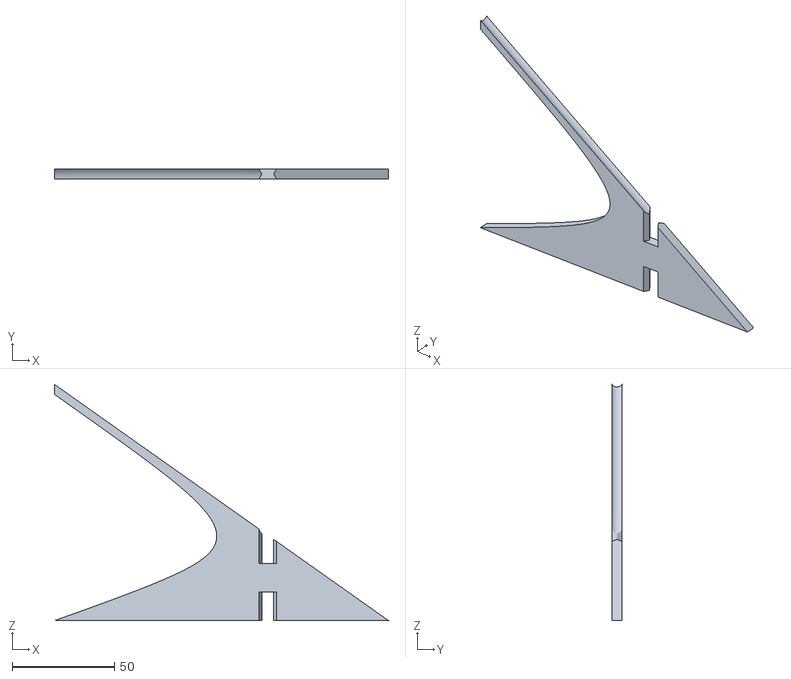
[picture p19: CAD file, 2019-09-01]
Mechanical/Interlocking Stand/Portable Stand B.stl
163.7 x 5.00 x 115.8

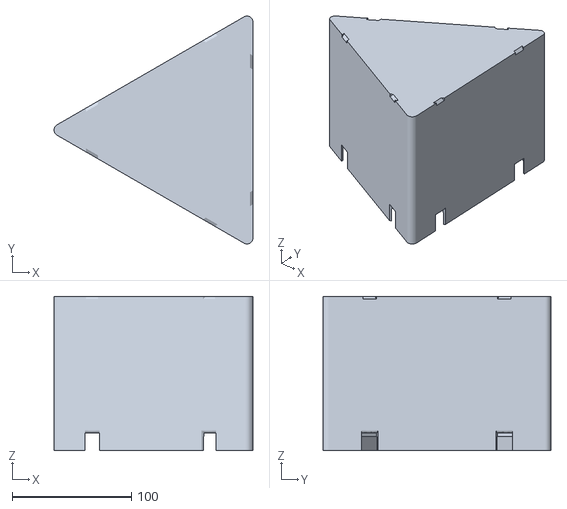
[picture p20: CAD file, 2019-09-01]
Mechanical/Static Stand/Travel Case/STC Lid v7.stl
166.8 x 191.0 x 129.4

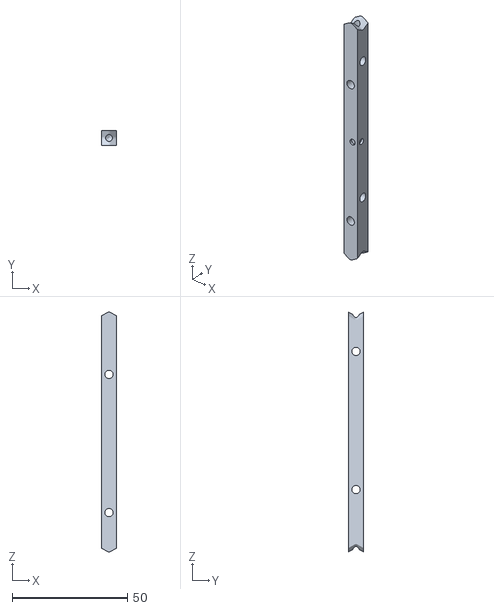
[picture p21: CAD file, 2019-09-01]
Mechanical/Cube/Skeleton Right Front v26.stl
6.60 x 6.60 x 104.2

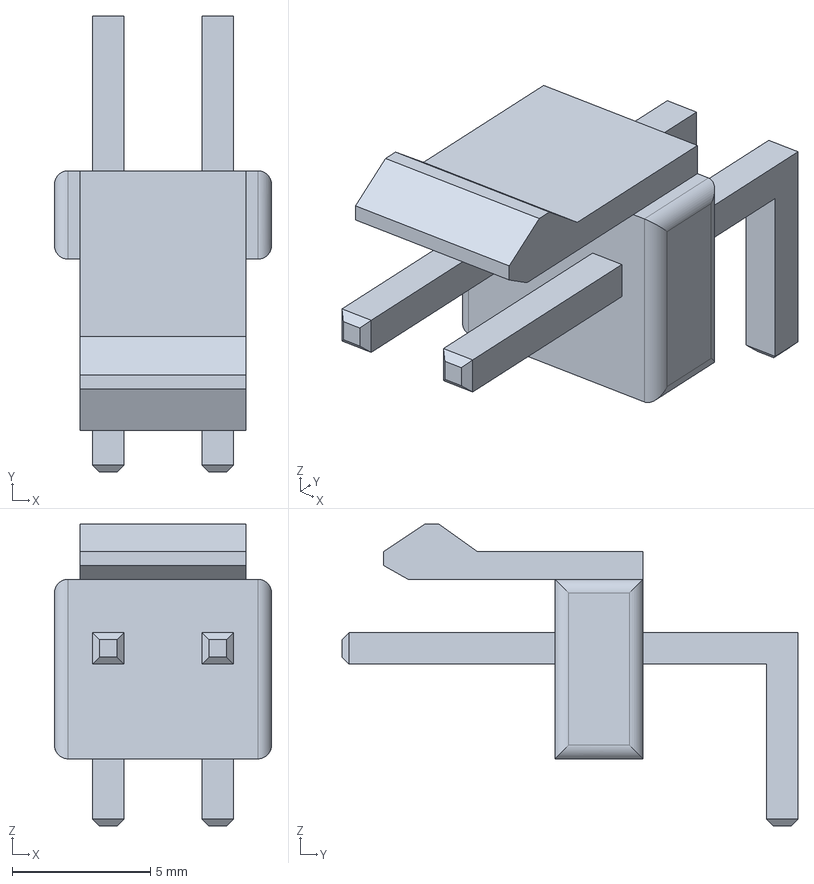
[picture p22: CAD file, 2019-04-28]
Power Board/v0.5/Power Board Models/JST-B2PS-VH.step
7.86 x 16.5 x 10.9 mm

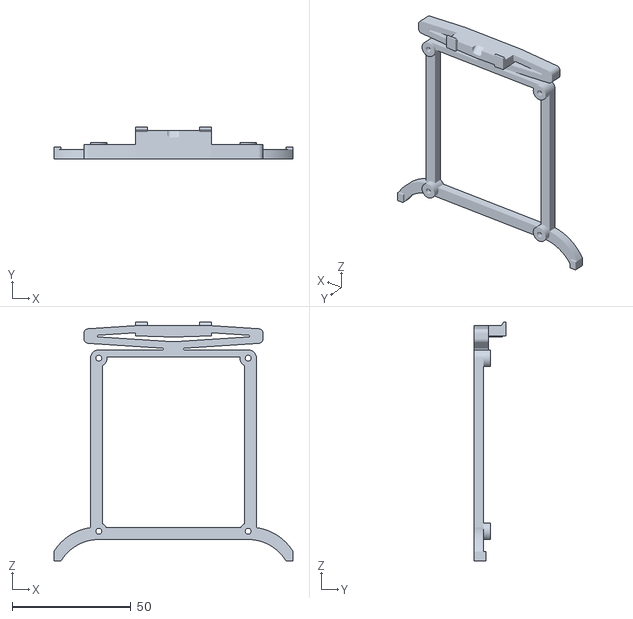
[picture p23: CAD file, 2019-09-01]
Mechanical/Cube/Rear Partition v55.stl
100.8 x 13.4 x 100.7

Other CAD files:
Mechanical/Interlocking Stand/Portable Stand C.stl
Power Board/v0.5/Power Board Models/DQY8_3P2X4P3.step
Power Board/v0.5/Power Board Models/JST_PUD_S10B-PUDSS-1_2x05x2.00mm_Angled.STEP
Mechanical/Cube/Upper Link v35.stl
Mechanical/Cube/Battery Carrier v64.stl
Mechanical/Cube/Frame v35.stl
Mechanical/Cube/Left Frame v40.stl
Mechanical/Cube/Left Hinge Pivot v63.stl
Mechanical/Cube/Lid v35.stl
Mechanical/Cube/Lower Link v35.stl
Mechanical/Cube/Pi Connector Clip 4 v4.stl
Mechanical/Cube/Pi Connector Cover 4 v4.f3d
Mechanical/Cube/Right Hinge Pivot v63.stl
Mechanical/Cube/Skeleton Bottom v59.stl
Mechanical/Cube/Skeleton Left Front v26.stl
Mechanical/Cube/Skeleton Left Rear v52.stl
Mechanical/Cube/Skeleton Right Rear v52.stl
Mechanical/Cube/Skeleton Top v53.stl
Mechanical/Interlocking Stand/Cube Stand Interlock v1.f3d
Mechanical/Static Stand/Static Stand v7.f3d
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

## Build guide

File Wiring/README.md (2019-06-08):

# Cube Wiring

The cube contains 10 PCBs with custom wiring between them.

## PCBs

 * Six LED panels
 * Power Board
 * Raspberry Pi
 * iCEBreaker FPGA
 * HUB75 PMOD

There is also a PCB inside the battery pack.

## Power Distribution

### Battery to power board

Use a 3 position JST VHR connector on the battery.

 Pin | Use
:---:|:---:
  1  | +V
  2  | N/C
  3  | GND

### Power board to LED panels

The LED panels are powered with 4 volts.

There is a direct wire from the power board to each LED panel.
The LED panel uses a 4 position JST VHR connector; the power board
uses a 2 position VHR.

 Panel Pin | Power Board Pin | Use
:---------:|:---------------:|:---:
 1         |        -        | N/C
 2         |        1        | +4V
 3         |        2        | GND
 4         |        -        | N/C

The wire to each panel is a different length to minimize cable clutter.

 Panel | Length
:-----:|:------:
Bottom | 130 mm
Front  | 240 mm
Back   |  95 mm +V<br>100 mm GND
Lid    | 200 mm
Left   |  70 mm
Right  |  60 mm

## Data Cables

### HUB75 data cables

The LED panels use a HUB75 interface.  HUB75 uses a 16 pin IDC
connector and ribbon cable.

Most of the LED panels use a "normal" cable where both IDC connectors
are on the same side of the ribbon.  But for mechanical reasons, two
of the cables have one connector upside down.  On all cables, pin 1
is connected to pin 1.

 From   | To     | Length | Shape
:-------|:-------|-------:|:-----:
 PMOD   | Left   |  70 mm | invert dest<br>(tabs out)
 Left   | Front  |  55 mm | normal
 Front  | Right  |  55 mm | normal
 Right  | Bottom | 155 mm | normal
 Bottom | Back   |  55 mm | normal
 Back   | Lid    | 105 mm | invert dest<br>(tabs out)

### Power board to Raspberry Pi

These two boards are connected by a ten conductor cable.
The power board provides the Pi with +5.25V power and ground,
and the Pi in turn provides the Power Board with +3.3V power.
There are also I&sup2;C connection and dedicated lines
for power sense, power control, and power alert (interrupt).

At the power board end, the connector is a 10 position JST PUD.
At the Raspberry Pi end, a 12 position Amphenol Mini-PV is used.
Each conductor is 67mm long before crimping.

Power Board Pin | Pi Pin | Color  | Function
---------------:|-------:|--------|----------
  1             |    1   | yellow | +3.3V
  2             |    2   | red    | +5.25V
  3             |    3   | green  | I&sup2;C SDA
  4             |    4   | red    | +5.25V
  5             |    5   | blue   | I&sub2;C SCL
  6             |    6   | black  | GND
  8             |    7   | blue   | Power Control
 \-             |    8   | -      | Reserved for serial console
  9             |    9   | black  | GND
 \-             |   10   | -      | Reserved for serial console
 10             |   11   | green  | Power Sense
  7             |   12   | white  | Power Alert

### Raspberry Pi to iCEBreaker FPGA

The Raspberry Pi connects to the iCEBreaker via USB.  Space is tight,
so a micro-USB connector with a small head is needed.  This one works.

[Cerrxian 9Inch Micro USB Cable Combo Left Angle Micro USB 5 Pin Male
to USB 2.0 Type A Right Angle Male Data Sync and Charge Cable](https://www.amazon.com/Cerrxian-Charge-Samsung-Motorola-Android/dp/B07P76Q8C2)

### iCEBreaker FPGA to PMOD

The PMOD interface is a board-to-board connection.  No cable needed.

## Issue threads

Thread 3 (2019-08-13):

PCB Inside battery pack?

greigs, 2019-08-13:
It seems like you are using a 4S 14.8v lipo battery, but the wiring doc states there is a PCB inside the battery pack as well. Can you share more details on this? Is it required?
I also noticed you are providing the panels 4V instead of 5V. Is there a reason for this?

(I am also hoping for 3D models of the frame, but not as big deal as the tech details)

daveythacher, 2020-10-28:
I am not sure about this power design. I think I know of a reason for why it drives 4V to panel. This may be high enough to prevent losing white color issues from panel current generators. Without swapping the resistors you may not be able to go much lower.

This all has to do with IV diode characteristics. Basically using switch mode regulators will allow more current for the same power if you lower voltage. (Ignoring conversion loses.) Lowering the voltage for diodes lowers the forward current. However these use constant current generators which are basically serial resistors that can change value against current/voltage. (There is a min voltage drop requirement, but is small and can be ignored in some cases. I am simplifying a lot here.)

So if you wanted you could drop below 20mA forward current. You could go down to 6mA which would require a lower voltage even with the driver min voltage applied. This would lower the power consumption in terms of voltage and current consumption. Switch mode is basically power in  equals power out divided by efficiency. Therefore lowering the power out requirement lowers the power in requirement to meet battery pack design.

Now there are other games you can play. However this can be more expensive. They require you look at other things too. For example a huge cap could lower a high current speak into a lower average spike. Also conversion voltage/current in switch mode can drive efficiency value.

The issues I see are white color balance, peak power, number of color steps, FPS performance, thermal, etc. The ice40 to my knowledge is not fast enough to support 24 bit color. To my knowledge the panels are not fast enough to support 24 bit color for 64x64, that ends with 32x64. (Assuming 95 frame refresh on panel)

I am not an expert on this. So take it with a grain of salt. I do have some understanding though.

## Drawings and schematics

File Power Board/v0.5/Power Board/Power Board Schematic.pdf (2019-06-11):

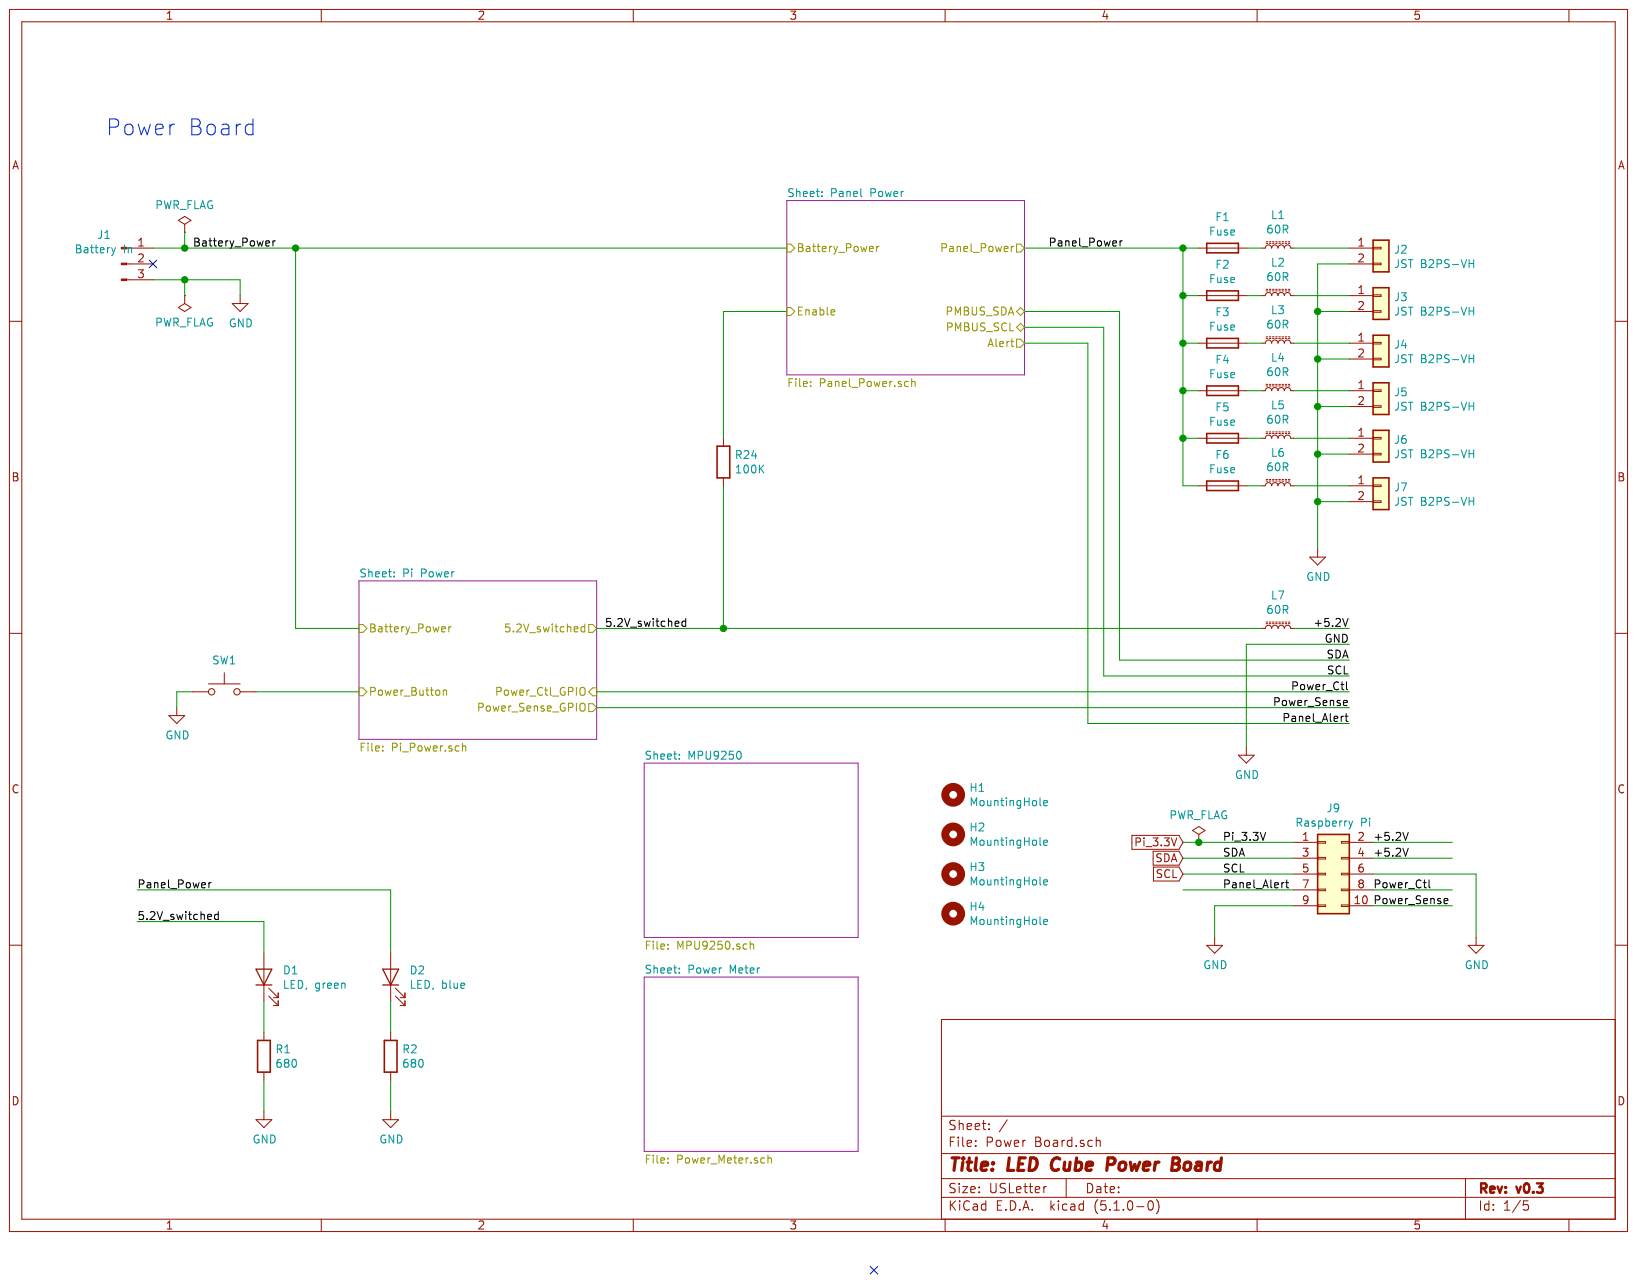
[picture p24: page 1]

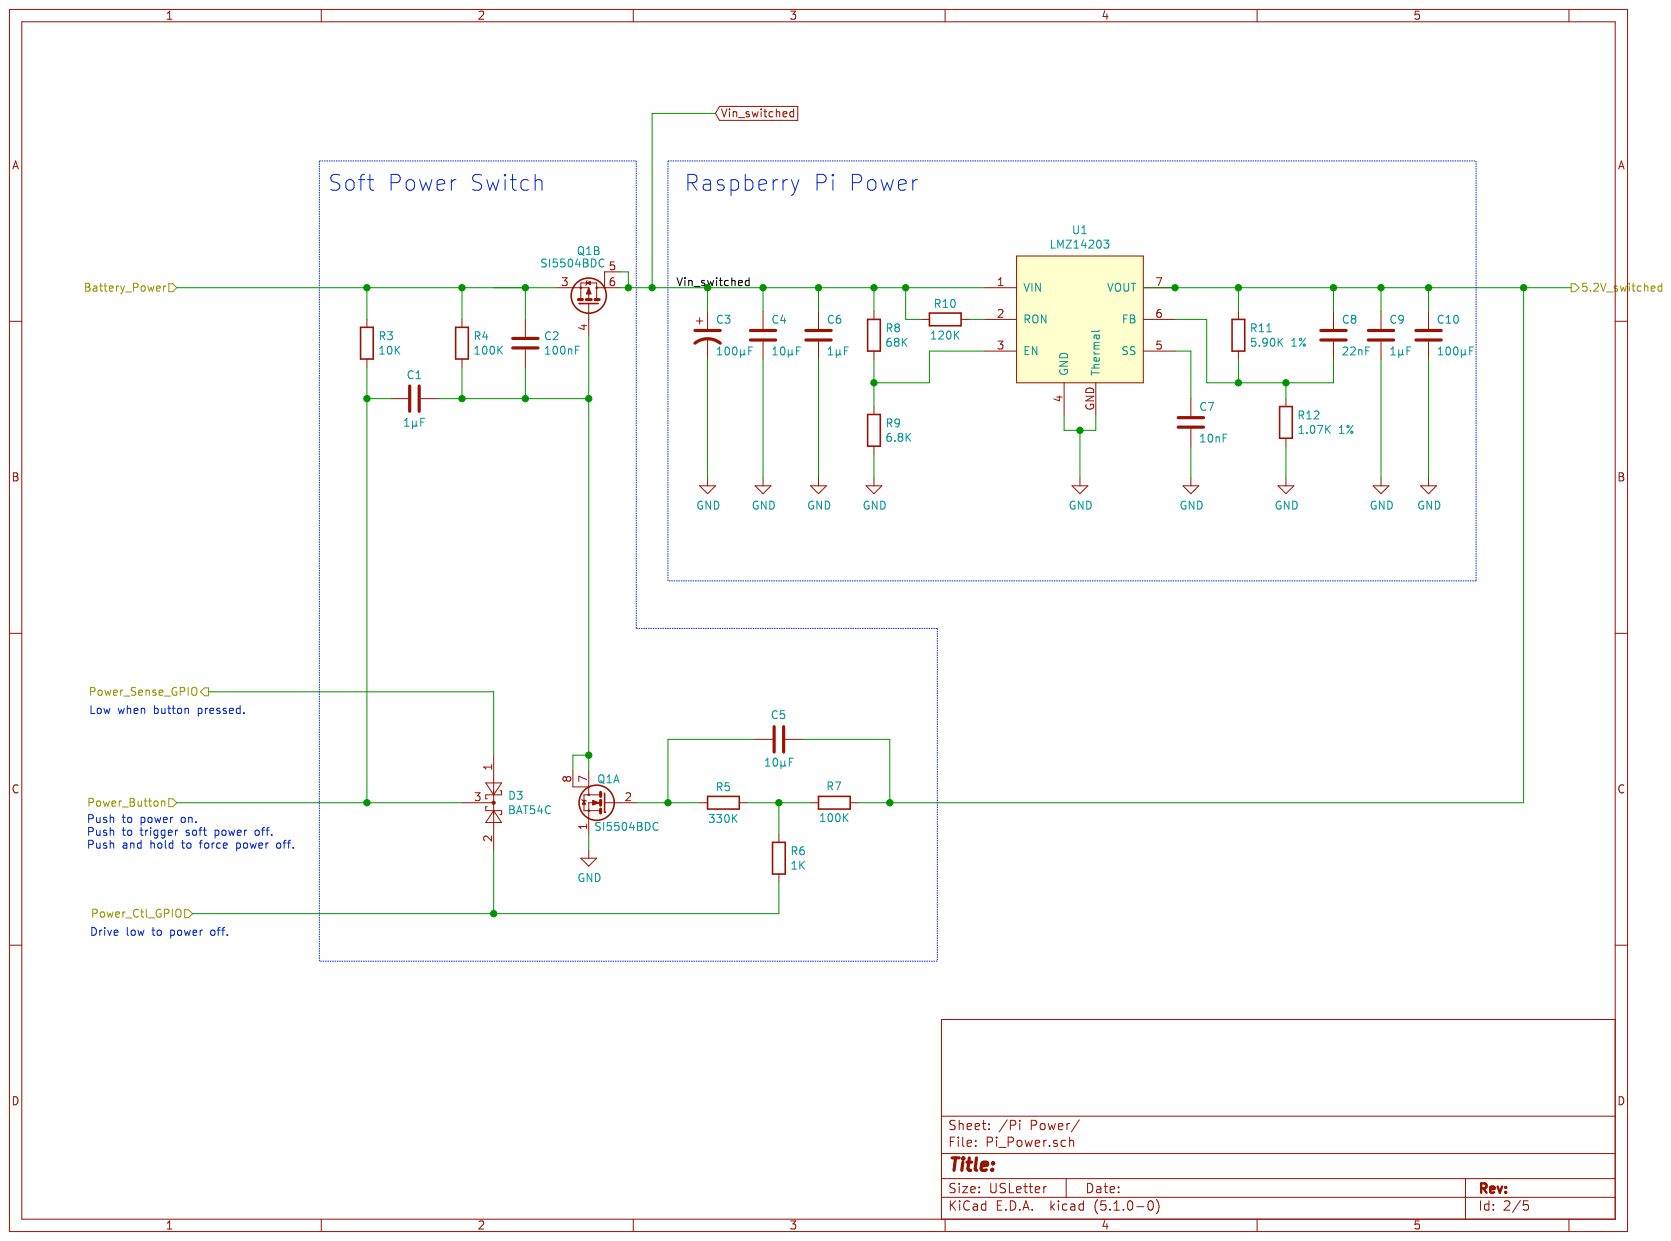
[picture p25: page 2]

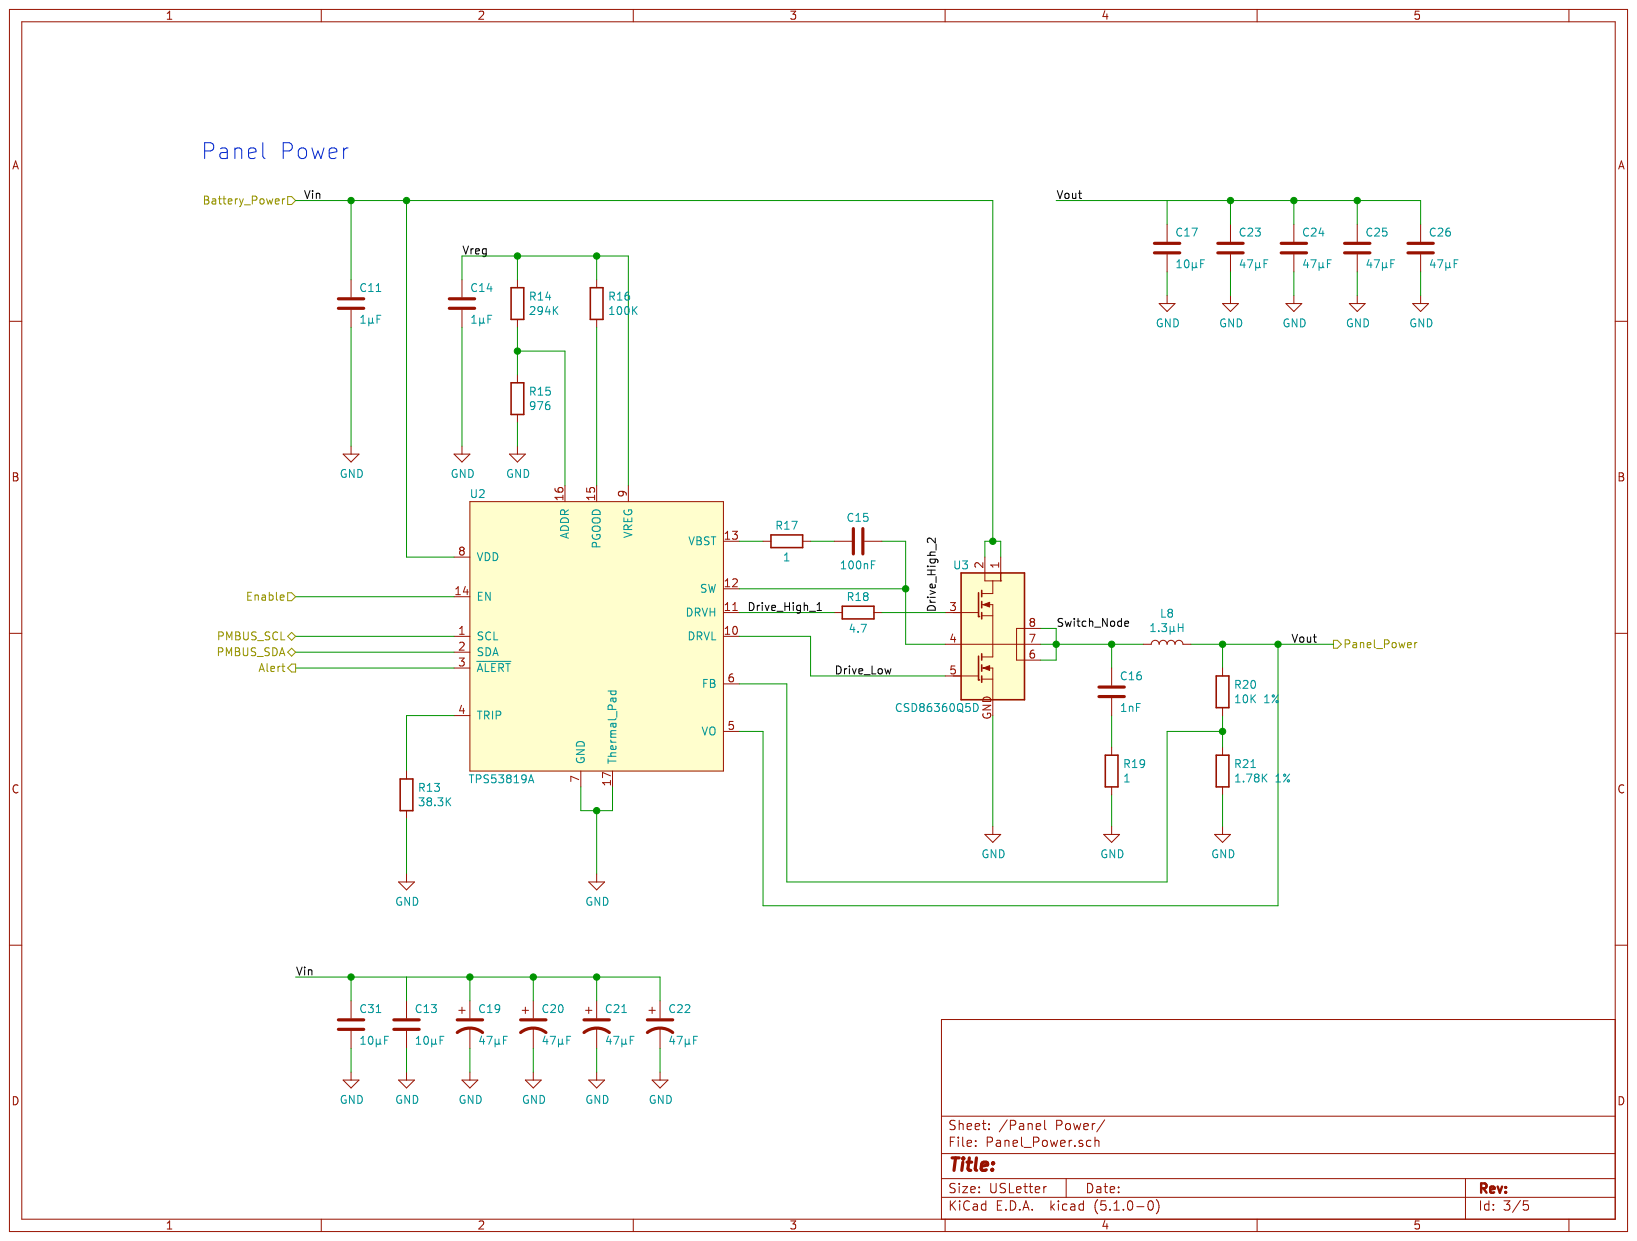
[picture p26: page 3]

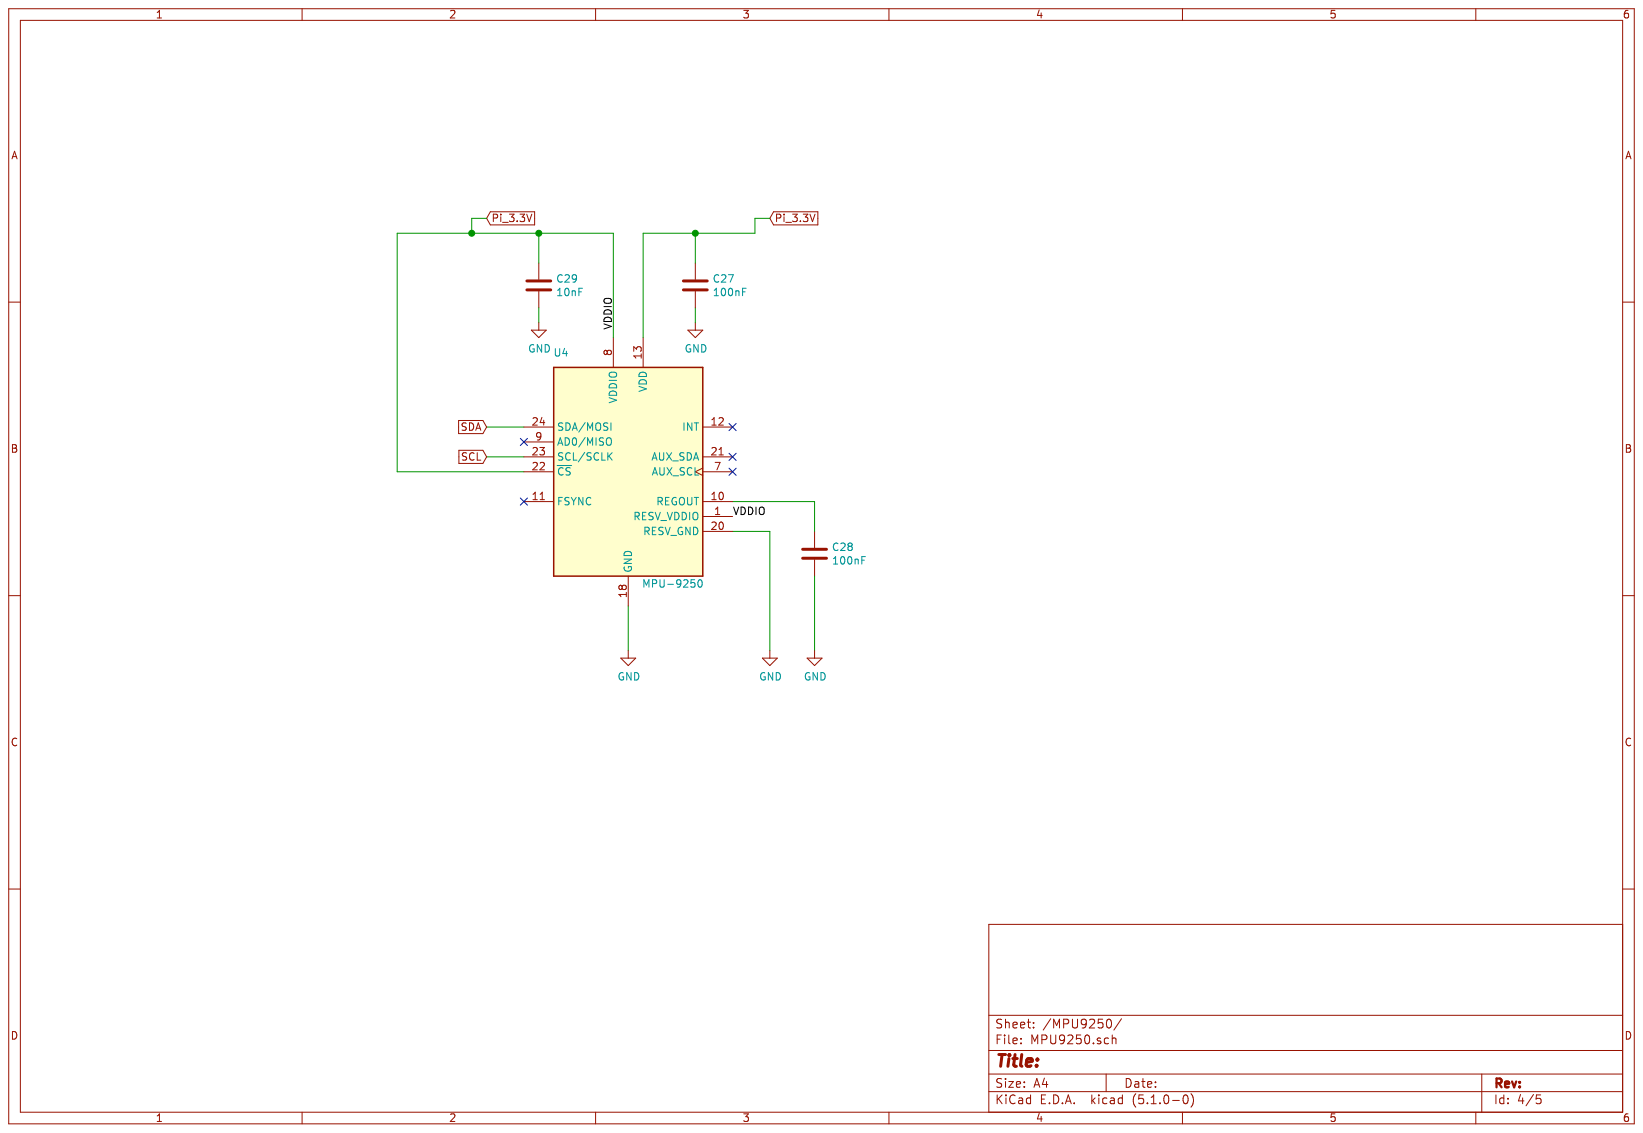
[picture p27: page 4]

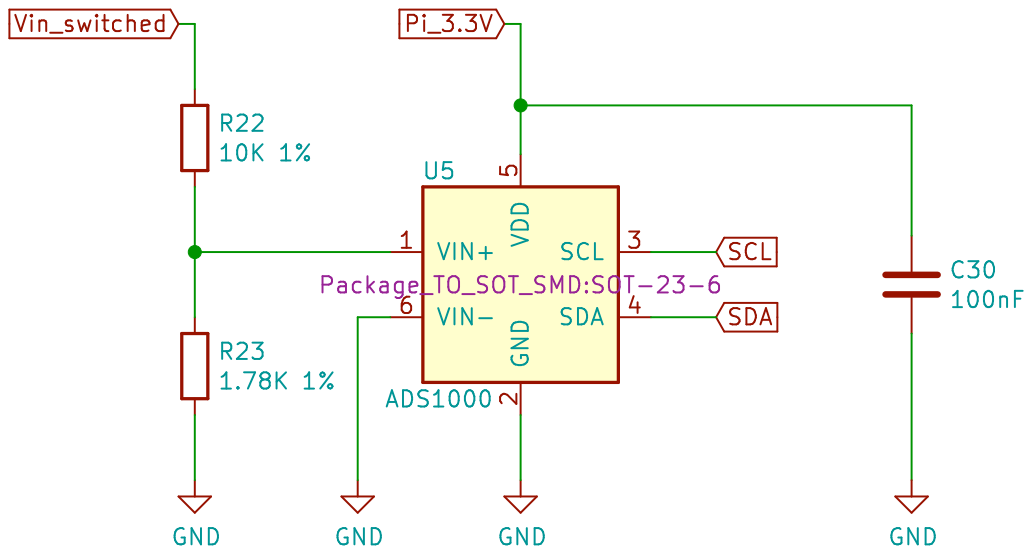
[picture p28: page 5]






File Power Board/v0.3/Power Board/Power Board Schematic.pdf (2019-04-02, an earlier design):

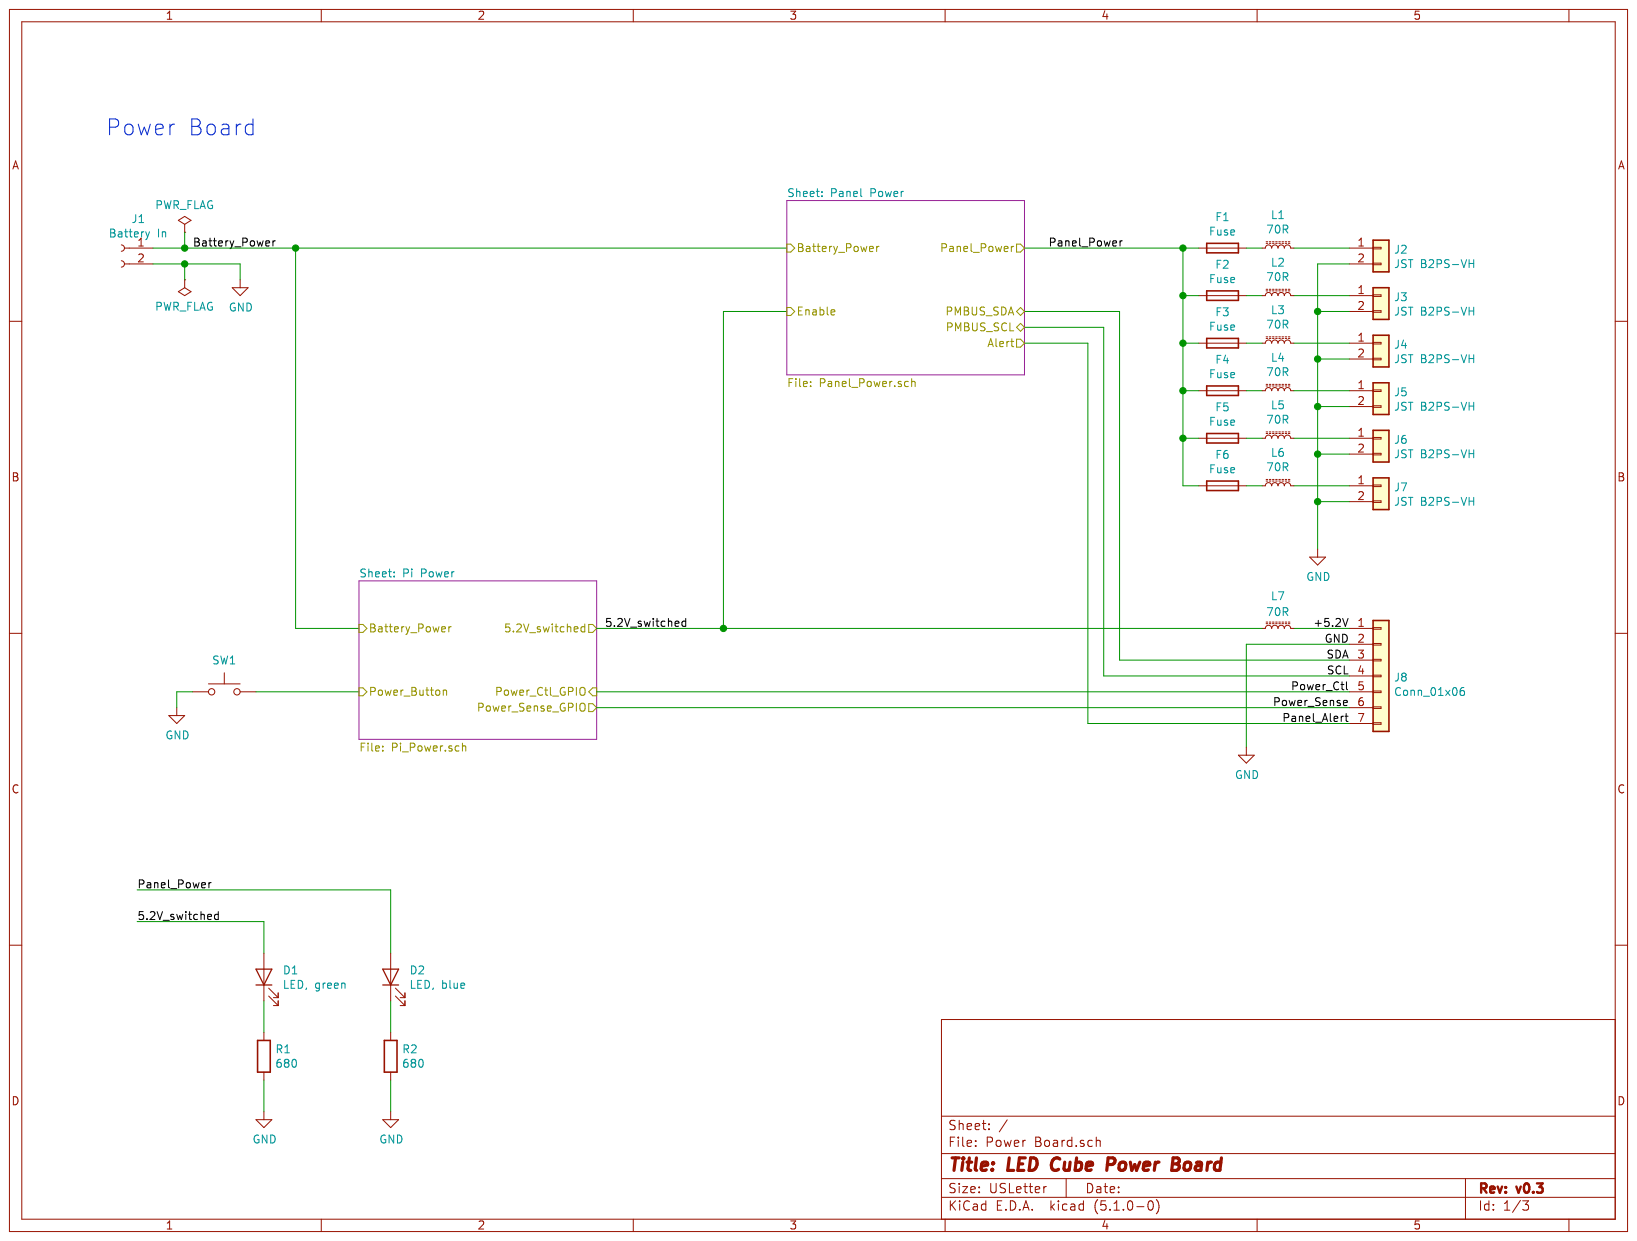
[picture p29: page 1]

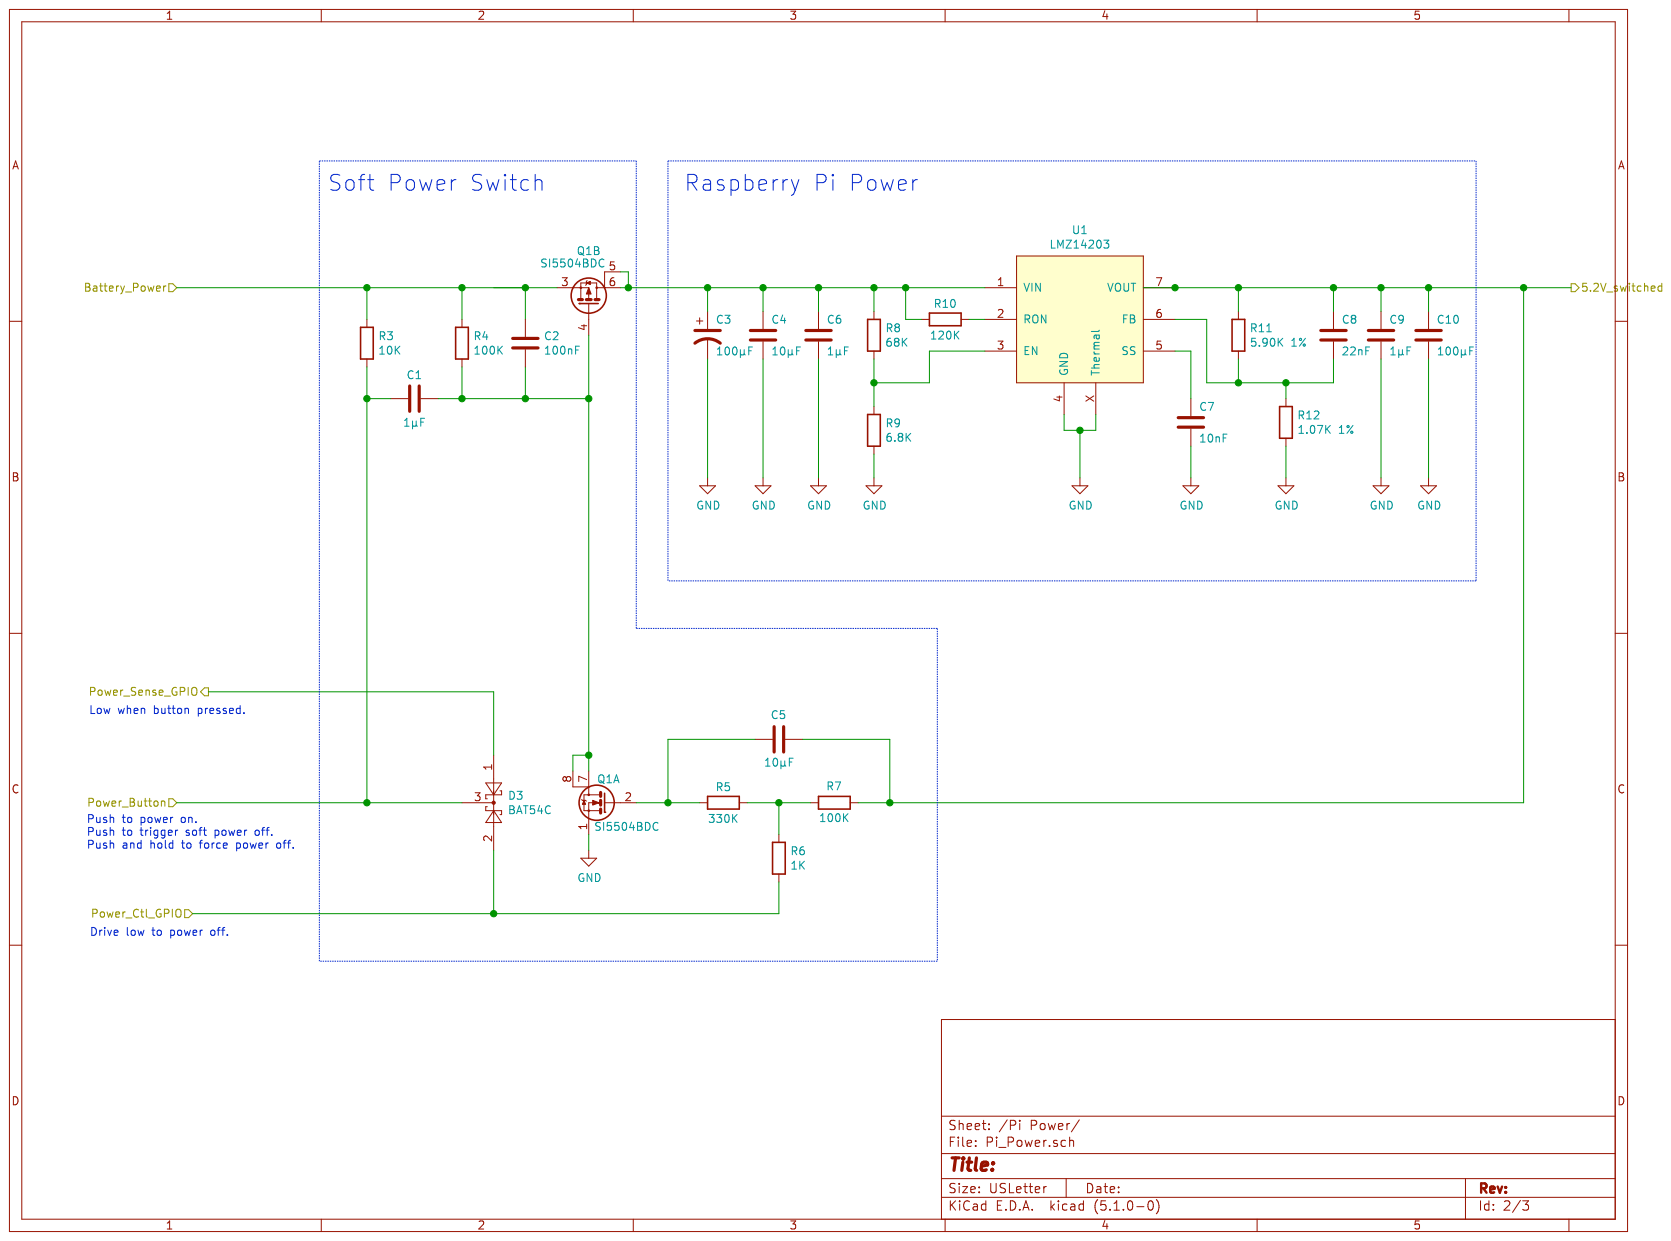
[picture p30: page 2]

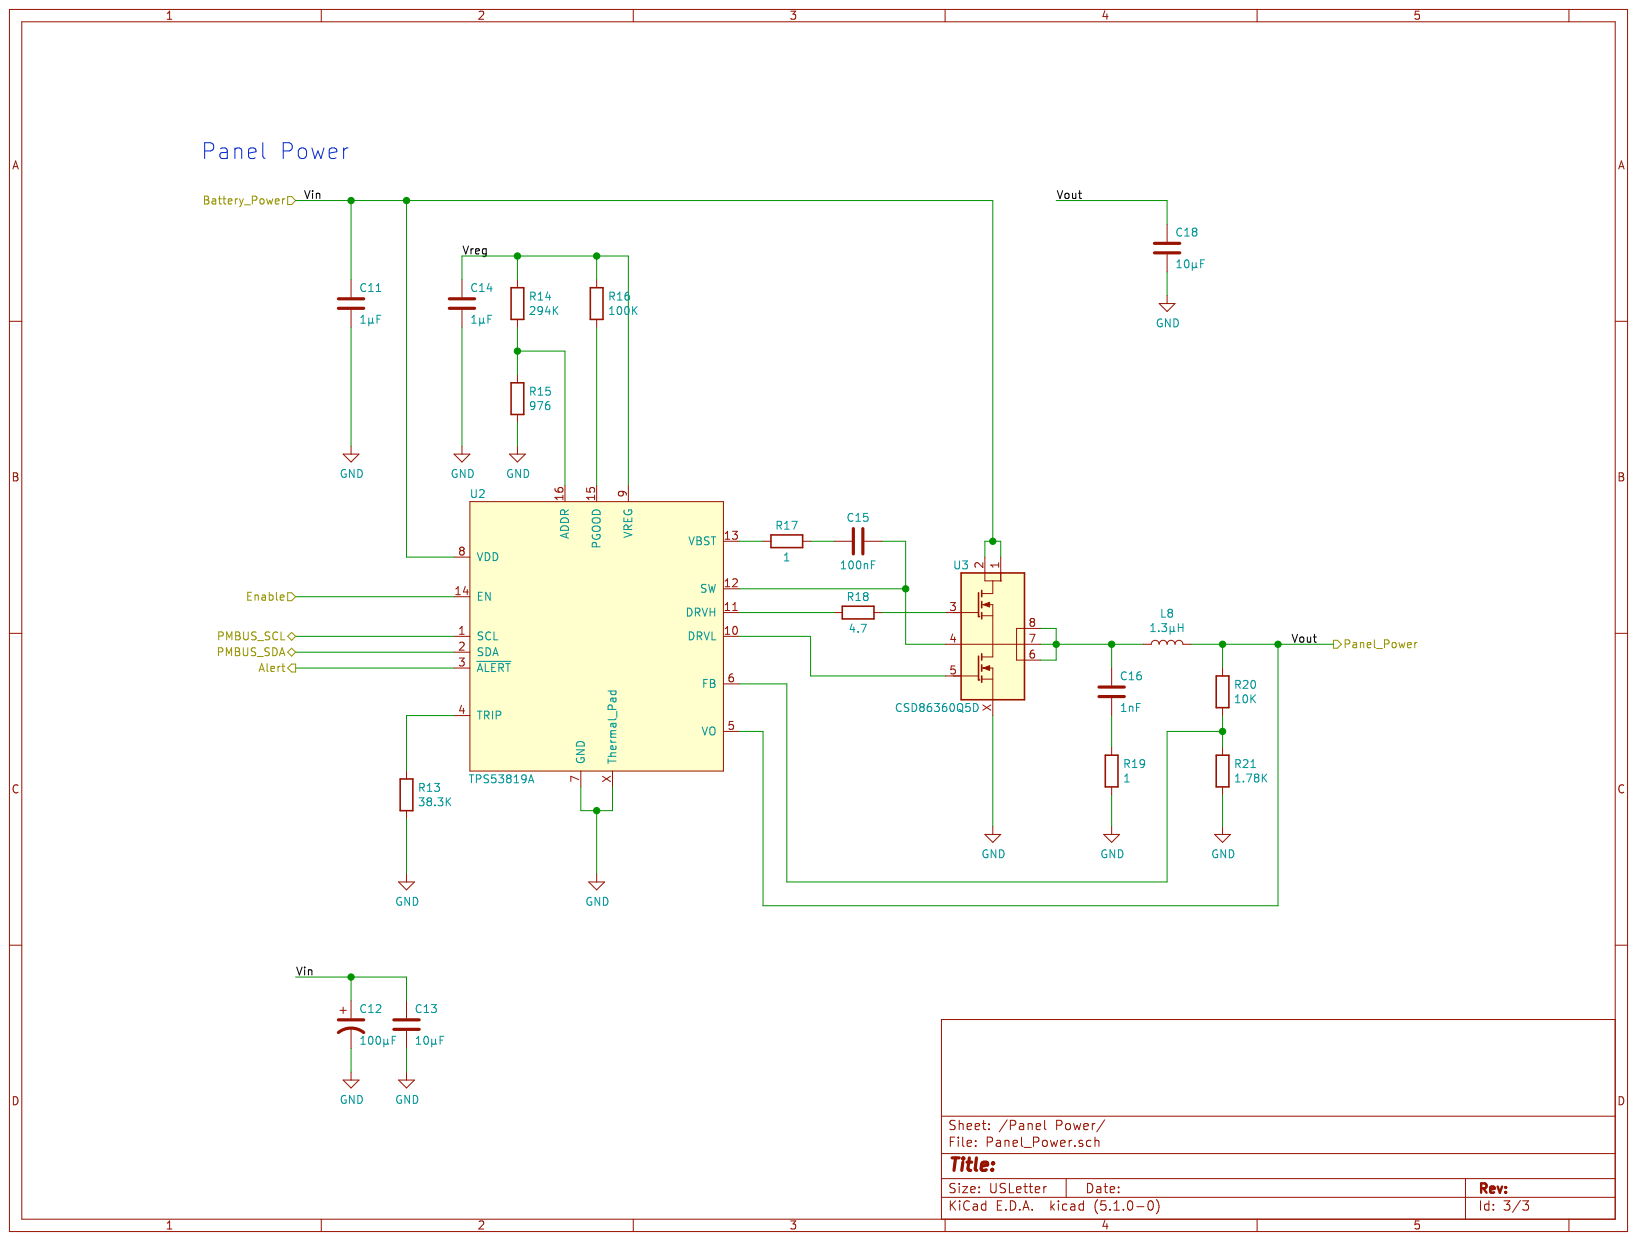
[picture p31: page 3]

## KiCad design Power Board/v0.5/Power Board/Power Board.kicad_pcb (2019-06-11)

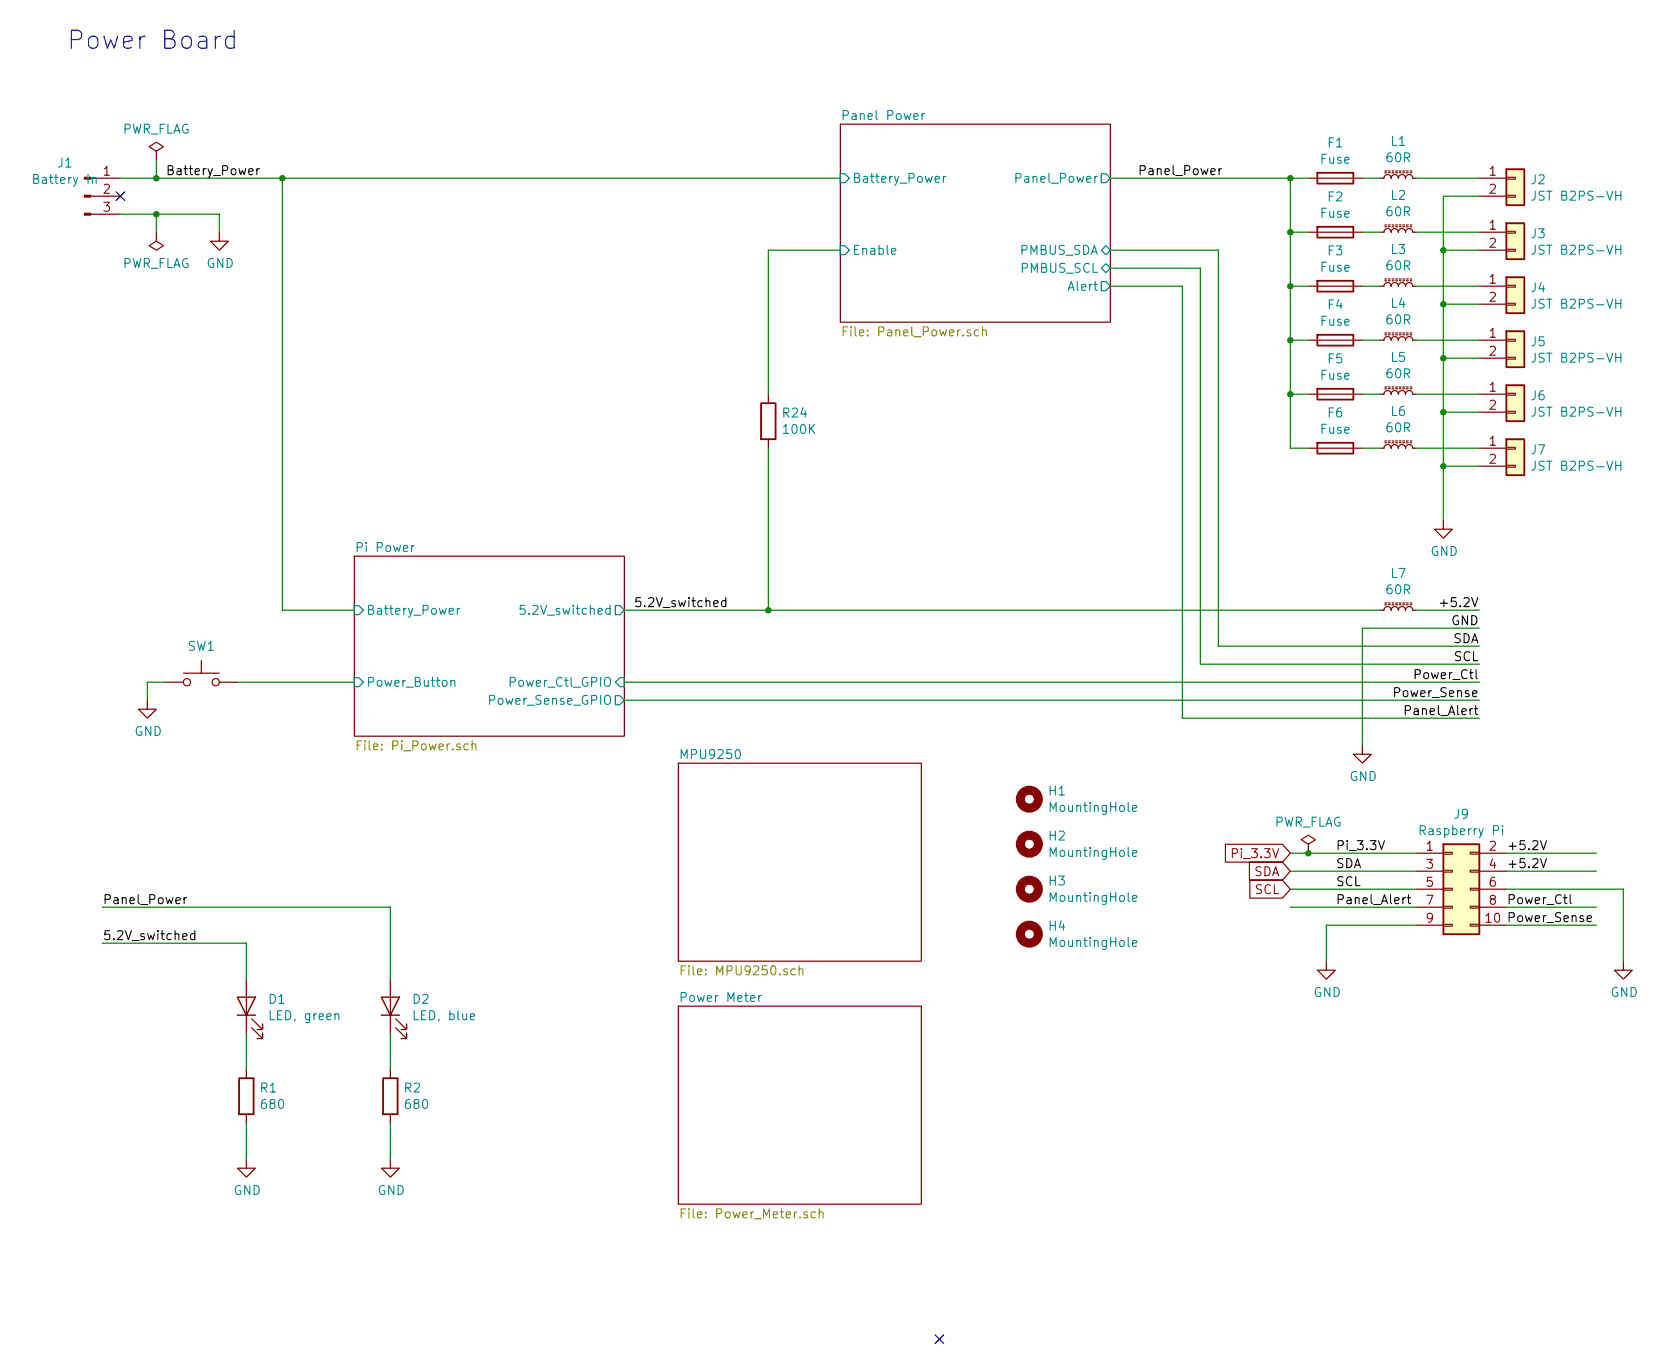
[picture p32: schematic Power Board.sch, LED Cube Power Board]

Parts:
D1: LED, green; LED_0603_1608Metric; Part No. LG Q971-KN-1
D2: LED, blue; LED_0603_1608Metric; Part No. LB Q39G-L2N2-35-1
F1, F2, F3, F4, F5, F6: Fuse; Fuse_1206_3216Metric; Part No. NANOSMD400LR-C-2; Digikey No. F9967CT-ND
H1, H2, H3, H4: MountingHole; MountingHole_2.7mm_M2.5
J1: Battery In; JST_VH_B3PS-VH_1x03_P3.96mm_Horizontal; Part No. B3PS-VH(LF)(SN); Digikey No. 455-1649-ND
J2, J3, J4, J5, J6, J7: JST B2PS-VH; JST_VH_B2PS-VH_1x02_P3.96mm_Horizontal; Part No. B2PS-VH(LF)(SN); Digikey No. 455-1648-ND
J9: Raspberry Pi; JST_PUD_S10B-PUDSS-1_2x05_P2.00mm_Horizontal; Part No. S10B-PUDSS-1(LF)(SN); Digikey No. 455-2486-ND
L1, L2, L3, L4, L5, L6, L7: 60R; L_1206_3216Metric; Part No. FBMJ3216HM600-T; Digikey No. 587-1770-1-ND
R1, R2: 680; R_0603_1608Metric_Pad1.05x0.95mm_HandSolder; Part No. RC0603JR-07680R
R24: 100K; R_0603_1608Metric; Part No. RC0603JR-07100K
SW1: SW_Push; PTS645-Vx-39-2; Part No. PTS645VK39-2 LFS; Digikey No. CKN10053-ND

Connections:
/5.2V_switched: D1.2 (A), L7.1, R24.2; also elsewhere on the board
/+5.2V: J9.2, J9.4, L7.2
/Battery_Power: J1.1; also elsewhere on the board
/Panel Power/Enable: R24.1; also elsewhere on the board
/Panel_Alert: J9.7; also elsewhere on the board
/Panel_Power: D2.2 (A), F1.2, F2.2, F3.2, F4.2, F5.2, F6.2; also elsewhere on the board
/Pi Power/Power_Button: SW1.2; also elsewhere on the board
/Power_Ctl: J9.8; also elsewhere on the board
/Power_Sense: J9.10; also elsewhere on the board
GND: J1.3, J2.2, J3.2, J4.2, J5.2, J6.2, J7.2, J9.6, J9.9, R1.2, R2.2, SW1.1; also elsewhere on the board
unnamed: D1.1 (K), R1.1
unnamed: D2.1 (K), R2.1
unnamed: F1.1, L1.1
unnamed: F2.1, L2.1
unnamed: F3.1, L3.1
unnamed: F4.1, L4.1
unnamed: F5.1, L5.1
unnamed: F6.1, L6.1
unnamed: J2.1, L1.2
unnamed: J3.1, L2.2
unnamed: J4.1, L3.2
unnamed: J5.1, L4.2
unnamed: J6.1, L5.2
unnamed: J7.1, L6.2
Pi_3.3V: J9.1; also elsewhere on the board
SCL: J9.5; also elsewhere on the board
SDA: J9.3; also elsewhere on the board

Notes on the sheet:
Power Board

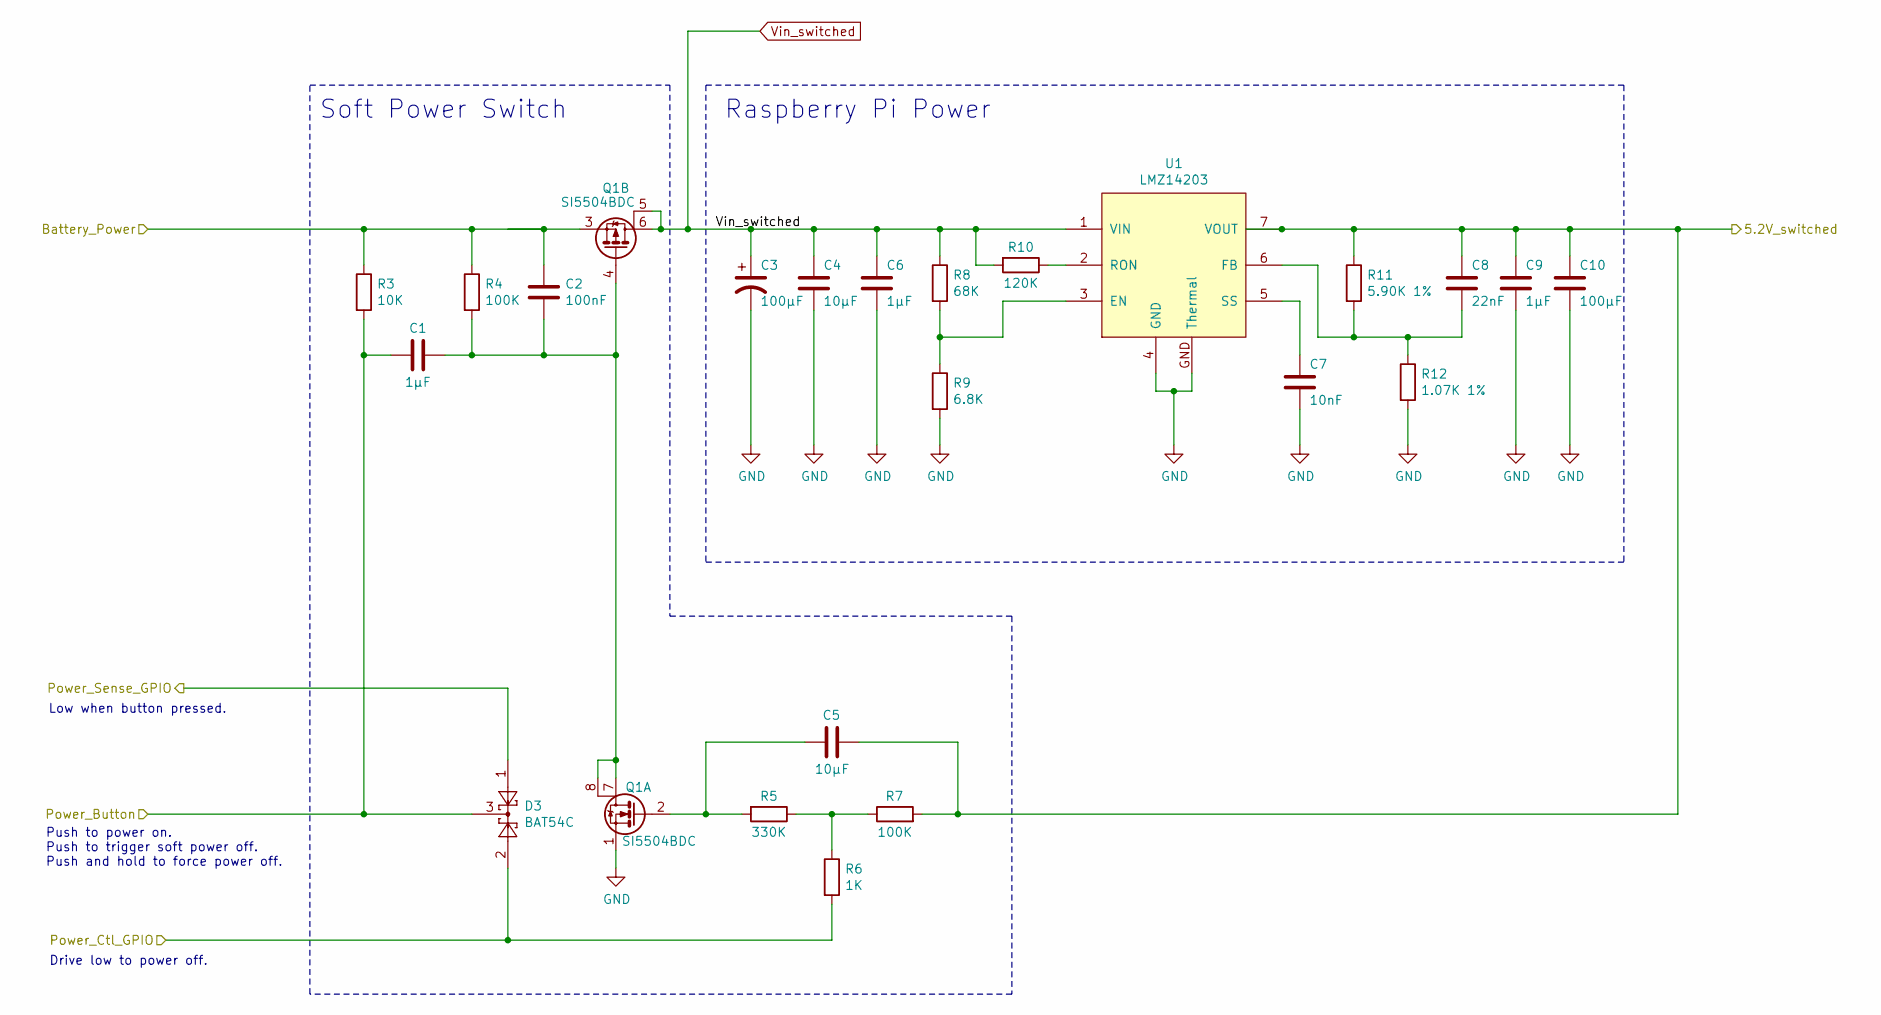
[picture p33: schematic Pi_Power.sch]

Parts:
C1, C6, C9: 1µF; C_0805_2012Metric; Part No. GMK212B7105KG-T; Digikey No. 587-1438-1-ND
C2: 100nF; C_0805_2012Metric; Part No. CGA4J2X7R2A104K125AA; Digikey No. 445-5827-1-ND
C3: 100µF; CP_Elec_8x10; Part No. EDK107M050A9MAA; Digikey No. 399-6672-1-ND
C4, C5: 10µF; C_0805_2012Metric; Part No. GRM21BR61E106MA73L; Digikey No. 490-10748-1-ND
C7: 10nF; C_0603_1608Metric; Part No. GRM188R71H103KA01D
C8: 22nF; C_0603_1608Metric; Part No. 885012206091; Digikey No. 732-8009-1-ND
C10: 100µF; C_1210_3225Metric; Part No. LMK325BJ107MM-T; Digikey No. 587-1965-1-ND
D3: BAT54C; SOT-23; Part No. BAT54CTA; Digikey No. BAT54CCT-ND
Q1: SI5504BDC; 1206-8_or_SO-8; Part No. SI5504BDC-T1-GE3; Digikey No. SI5504BDC-T1-GE3CT-ND
R3: 10K; R_0603_1608Metric; Part No. RC0603JR-0710K
R4, R7: 100K; R_0603_1608Metric; Part No. RC0603JR-07100K
R5: 330K; R_0603_1608Metric; Part No. RC0603JR-07330K
R6: 1K; R_0603_1608Metric; Part No. RC0603JR-071K
R8: 68K; R_0603_1608Metric; Part No. RC0603JR-0768K
R9: 6.8K; R_0603_1608Metric; Part No. RC0603JR-076K8
R10: 120K; R_0603_1608Metric; Part No. RC0603JR-07120K
R11: 5.90K 1%; R_0603_1608Metric; Part No. ERJ-3EKF5901V; Digikey No. P5.90KHCT-ND
R12: 1.07K 1%; R_0603_1608Metric; Part No. ERJ-3EKF1071V; Digikey No. P1.07KHCT-ND
U1: LMZ14203; TO-PMOD_7; Part No. LMZ14203TZX-ADJ/NOPB; Digikey No. LMZ14203TZX-ADJ/NOPBCT-ND

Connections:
/5.2V_switched: C5.2, C8.1, C9.1, C10.1, R7.2, R11.1, U1.7 (VOUT); also elsewhere on the board
/Battery_Power: C2.1, Q1.3 (1), R3.1, R4.1; also elsewhere on the board
/Pi Power/Power_Button: C1.2, D3.3, R3.2; also elsewhere on the board
/Power_Ctl: D3.2, R6.2; also elsewhere on the board
/Power_Sense: D3.1; also elsewhere on the board
GND: C3.2, C4.2, C6.2, C7.2, C9.2, C10.2, Q1.1 (S), R9.2, R12.2, U1.4 (GND), U1.GND (Thermal); also elsewhere on the board
unnamed: C1.1, C2.2, Q1.4 (G), Q1.7 (D), Q1.8 (D), R4.2
unnamed: C5.1, Q1.2 (G), R5.2
unnamed: C7.1, U1.5 (SS)
unnamed: C8.2, R11.2, R12.1, U1.6 (FB)
unnamed: R5.1, R6.1, R7.1
unnamed: R8.2, R9.1, U1.3 (EN)
unnamed: R10.1, U1.2 (RON)
Vin_switched: C3.1, C4.1, C6.1, Q1.5 (D), Q1.6 (D), R8.1, R10.2, U1.1 (VIN); also elsewhere on the board

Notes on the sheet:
Raspberry Pi Power
Push to power on. Push to trigger soft power off. Push and hold to force power off.
Drive low to power off.
Soft Power Switch
Low when button pressed.

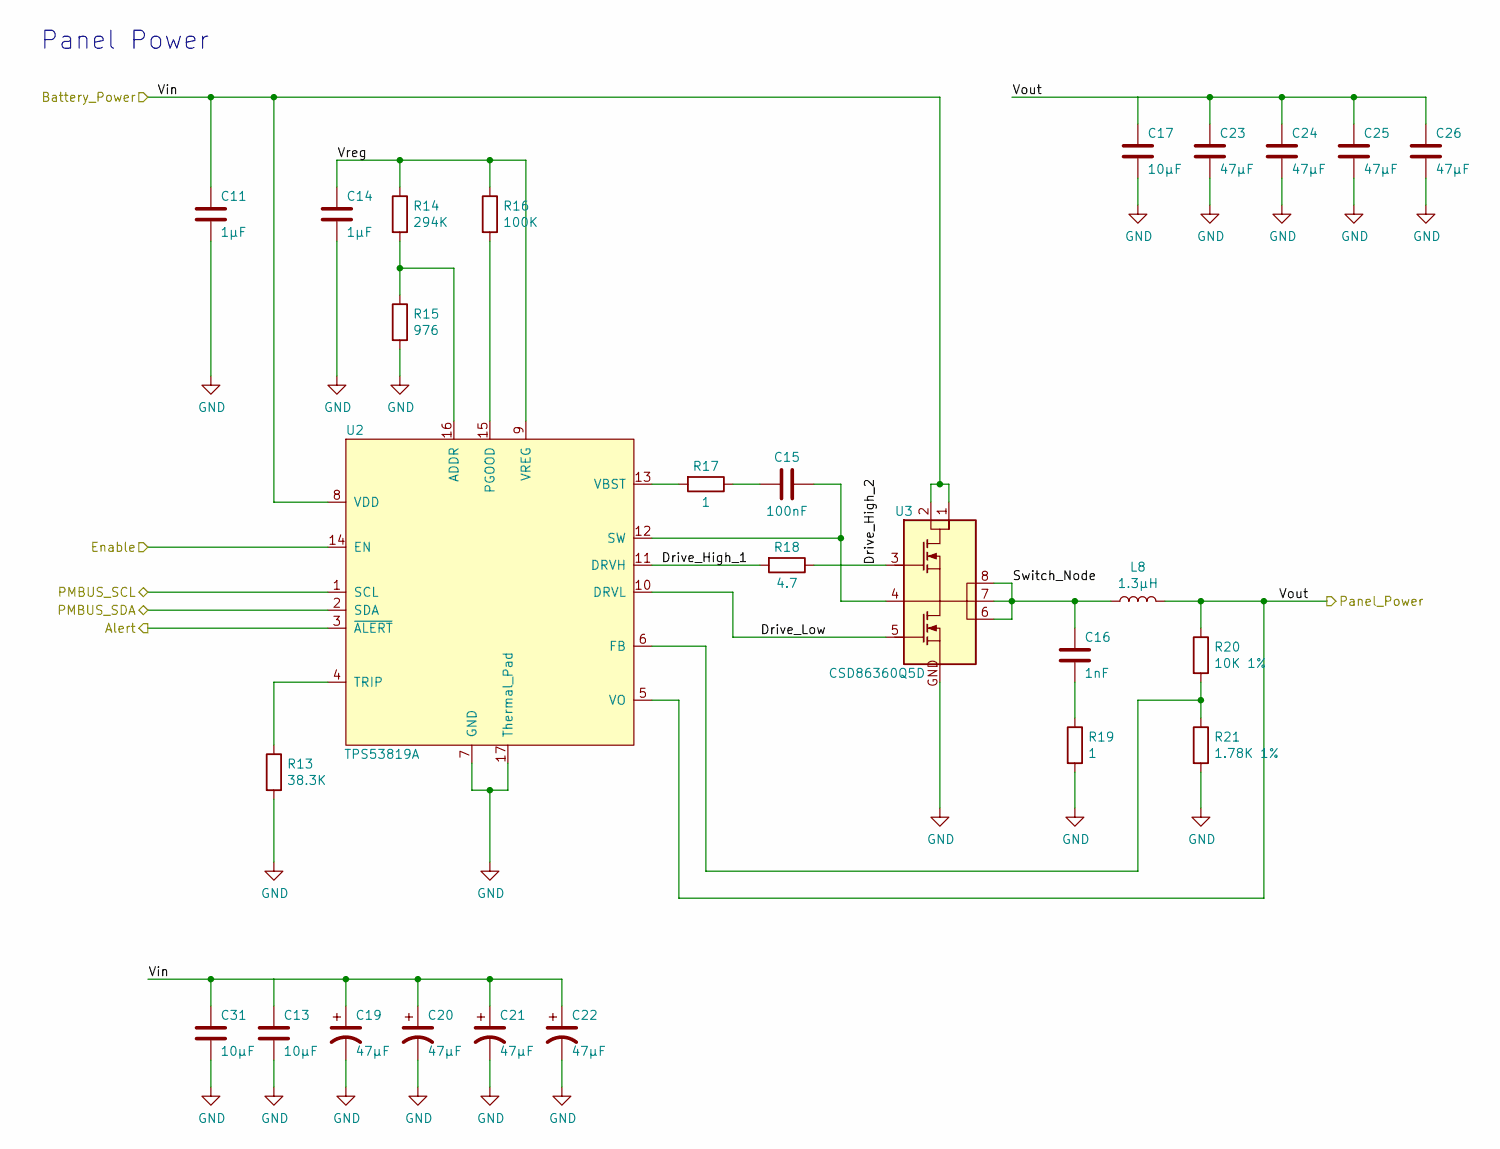
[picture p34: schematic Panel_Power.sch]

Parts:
C11, C14: 1µF; C_0805_2012Metric; Part No. GMK212B7105KG-T; Digikey No. 587-1438-1-ND
C13, C17, C31: 10µF; C_1206_3216Metric; Part No. GRM21BR61E106MA73L; Digikey No. 490-10748-1-ND
C15: 100nF; C_0805_2012Metric; Part No. CGA4J2X7R2A104K125AA; Digikey No. 445-5827-1-ND
C16: 1nF; C_0603_1608Metric; Part No. C0603C102J5RACTU; Digikey No. 399-1083-1-ND
C19, C20, C21, C22: 47µF; CP_OSCON_Poly_F12; Part No. 35SVPD47M; Digikey No. PCE5080CT-ND
C23, C24, C25, C26: 47µF; C_1210_3225Metric; Part No. GRM32EC81C476KE15L; Digikey No. 490-10531-1-ND
L8: 1.3µH; Coilcraft_XAL1580; Part No. XAL1580-132MEB; Digikey No. Mouser
R13: 38.3K; R_0603_1608Metric; Part No. RMCF0603FT38K3; Digikey No. RMCF0603FT38K3CT-ND
R14: 294K; R_0402_1005Metric; Part No. CRCW0402294KFKED; Digikey No. 541-294KLCT-ND
R15: 976; R_0402_1005Metric; Part No. CRCW0402976RFKED; Digikey No. 541-976LCT-ND
R16: 100K; R_0603_1608Metric; Part No. RC0603JR-07100K
R17, R19: 1; R_0805_2012Metric; Part No. CRCW08051R00FKEA; Digikey No. 541-1.00CCCT-ND
R18: 4.7; R_0805_2012Metric; Part No. ERJ-6RQF4R7V; Digikey No. P4.7DCT-ND
R20: 10K 1%; R_0603_1608Metric; Part No. RNCP0603FTD10K0; Digikey No. RNCP0603FTD10K0CT-ND
R21: 1.78K 1%; R_0603_1608Metric; Part No. RC0603FR-0717K8L; Digikey No. 311-17.8KHRCT-ND
U2: TPS53819A; VQFN-16-1EP_3x3mm_P0.5mm_EP1.68x1.68mm_ThermalVias; Part No. TPS53819ARGTR; Digikey No. 296-35480-1-ND
U3: CSD86360Q5D; Q5D; Part No. CSD86360Q5D; Digikey No. 296-35026-1-ND

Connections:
/Battery_Power: C11.1, C13.1, C19.1, C20.1, C21.1, C22.1, C31.1, U2.8 (VDD), U3.1 (VIN), U3.2 (VIN); also elsewhere on the board
/Panel Power/Drive_High_1: R18.2, U2.11 (DRVH)
/Panel Power/Drive_High_2: R18.1, U3.3 (TG)
/Panel Power/Drive_Low: U2.10 (DRVL), U3.5 (BG)
/Panel Power/Enable: U2.14 (EN); also elsewhere on the board
/Panel Power/Switch_Node: C16.1, L8.1, U3.6 (VSW), U3.7 (VSW), U3.8 (VSW)
/Panel Power/Vreg: C14.1, R14.1, R16.1, U2.9 (VREG)
/Panel_Alert: U2.3 (~ALERT); also elsewhere on the board
/Panel_Power: C17.1, C23.1, C24.1, C25.1, C26.1, L8.2, R20.1, U2.5 (VO); also elsewhere on the board
GND: C11.2, C13.2, C14.2, C17.2, C19.2, C20.2, C21.2, C22.2, C23.2, C24.2, C25.2, C26.2, C31.2, R13.2, R15.2, R19.2, R21.2, U2.7 (GND), U2.17 (Thermal_Pad), U3.GND; also elsewhere on the board
unnamed: C15.1, U2.12 (SW), U3.4 (TGR)
unnamed: C15.2, R17.1
unnamed: C16.2, R19.1
unnamed: R13.1, U2.4 (TRIP)
unnamed: R14.2, R15.1, U2.16 (ADDR)
unnamed: R16.2, U2.15 (PGOOD)
unnamed: R17.2, U2.13 (VBST)
unnamed: R20.2, R21.1, U2.6 (FB)
SCL: U2.1 (SCL); also elsewhere on the board
SDA: U2.2 (SDA); also elsewhere on the board

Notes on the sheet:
Panel Power

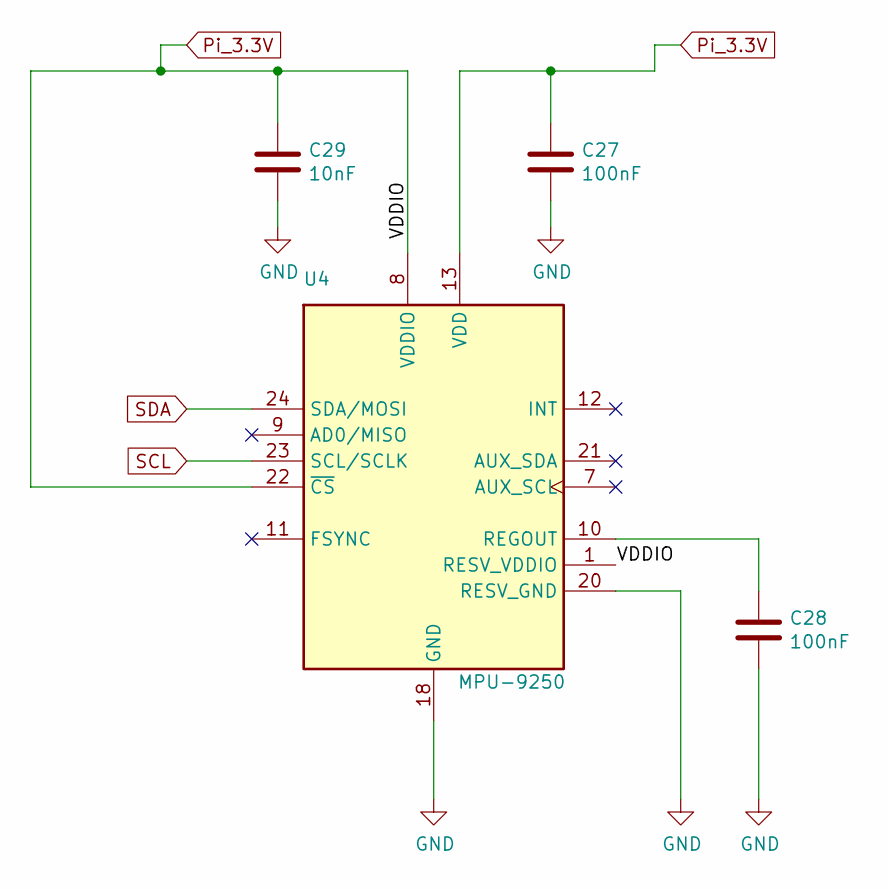
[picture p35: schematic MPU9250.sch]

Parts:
C27, C28: 100nF; C_0603_1608Metric; Part No. GRM188R71C104KA01D
C29: 10nF; C_0603_1608Metric; Part No. GRM188R71H103KA01D
U4: MPU-9250; InvenSense_QFN-24_3x3mm_P0.4mm; Part No. MPU-9250; Digikey No. 1428-1019-1-ND

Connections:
GND: C27.2, C28.2, C29.2, U4.18 (GND), U4.20 (RESV_GND); also elsewhere on the board
unnamed: C28.1, U4.10 (REGOUT)
Pi_3.3V: C27.1, C29.1, U4.1 (RESV_VDDIO), U4.8 (VDDIO), U4.13 (VDD), U4.22 (~CS); also elsewhere on the board
SCL: U4.23 (SCL/SCLK); also elsewhere on the board
SDA: U4.24 (SDA/MOSI); also elsewhere on the board

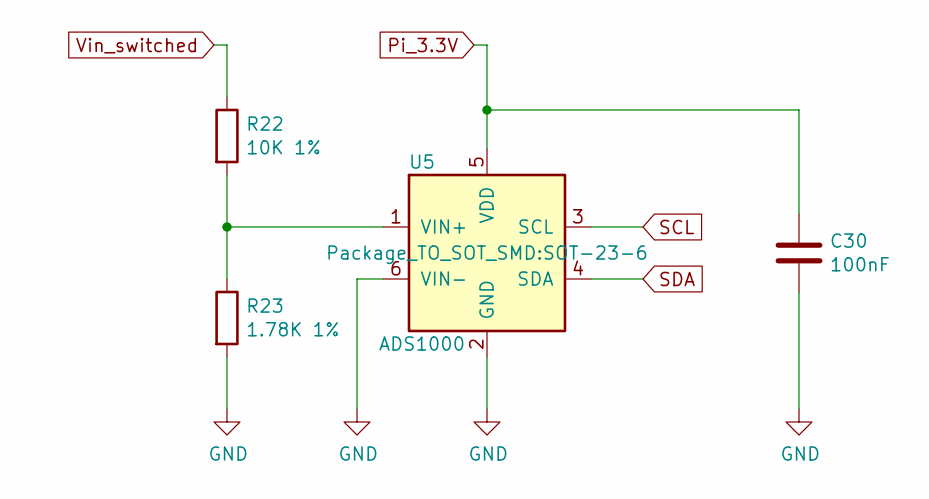
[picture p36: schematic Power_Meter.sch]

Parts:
C30: 100nF; C_0603_1608Metric; Part No. GRM188R71C104KA01D
R22: 10K 1%; R_0603_1608Metric; Part No. RNCP0603FTD10K0; Digikey No. RNCP0603FTD10K0CT-ND
R23: 1.78K 1%; R_0603_1608Metric; Part No. RC0603FR-0717K8L; Digikey No. 311-17.8KHRCT-ND
U5: ADS1000; SOT-23-6; Part No. ADS1000A0IDBVR; Digikey No. 296-38847-1-ND

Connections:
GND: C30.2, R23.2, U5.2 (GND), U5.6 (VIN-); also elsewhere on the board
unnamed: R22.2, R23.1, U5.1 (VIN+)
Pi_3.3V: C30.1, U5.5 (VDD); also elsewhere on the board
SCL: U5.3 (SCL); also elsewhere on the board
SDA: U5.4 (SDA); also elsewhere on the board
Vin_switched: R22.1; also elsewhere on the board

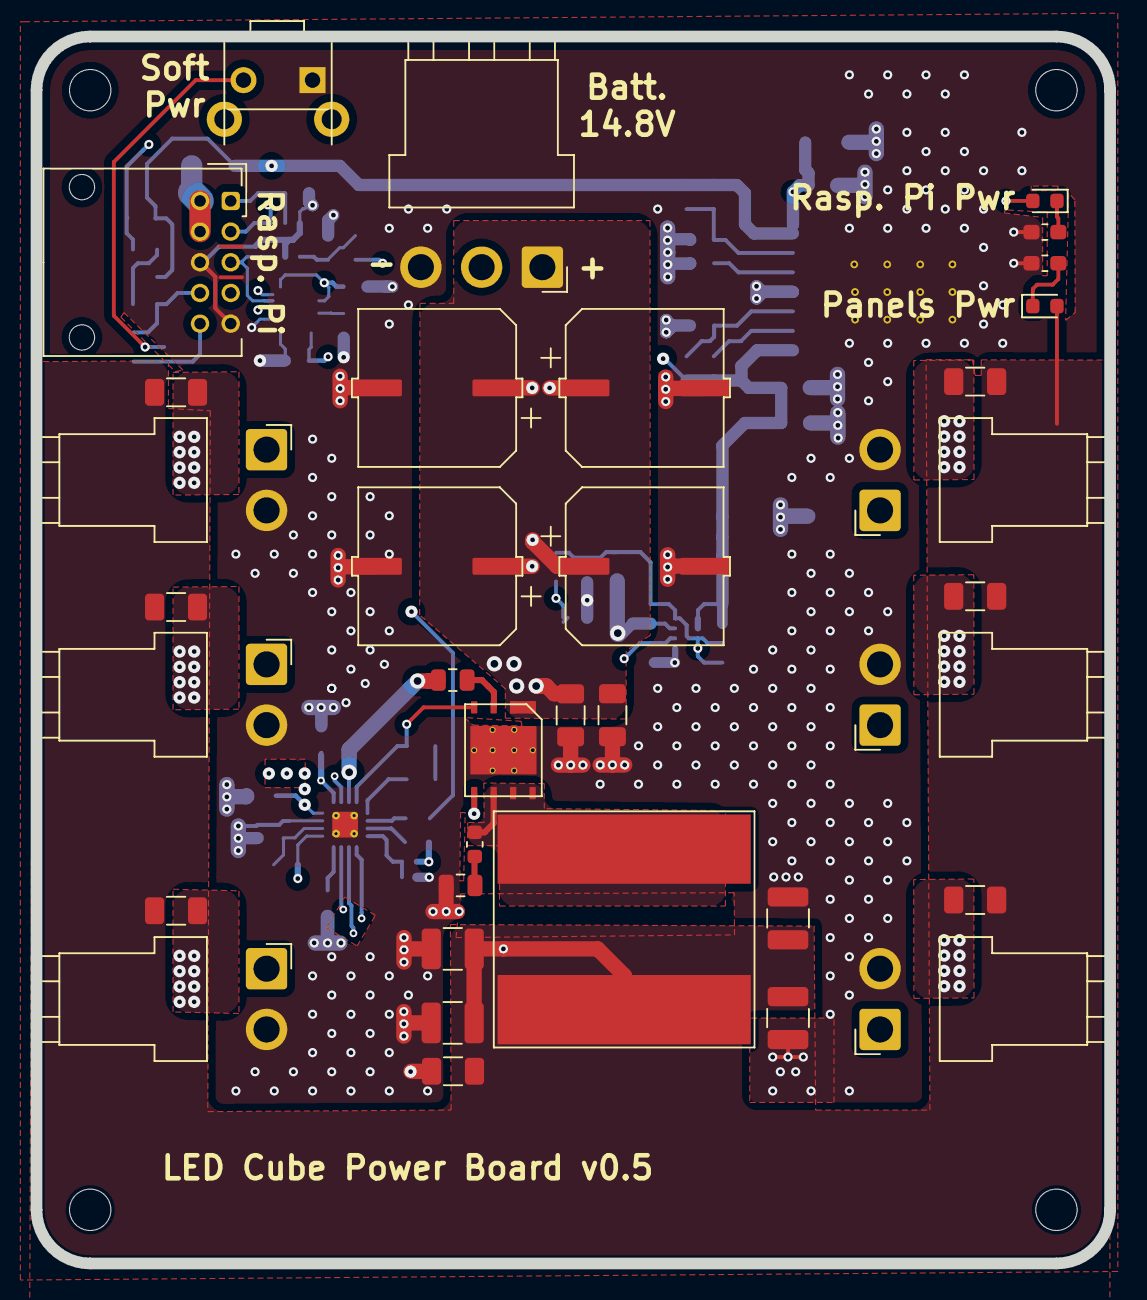
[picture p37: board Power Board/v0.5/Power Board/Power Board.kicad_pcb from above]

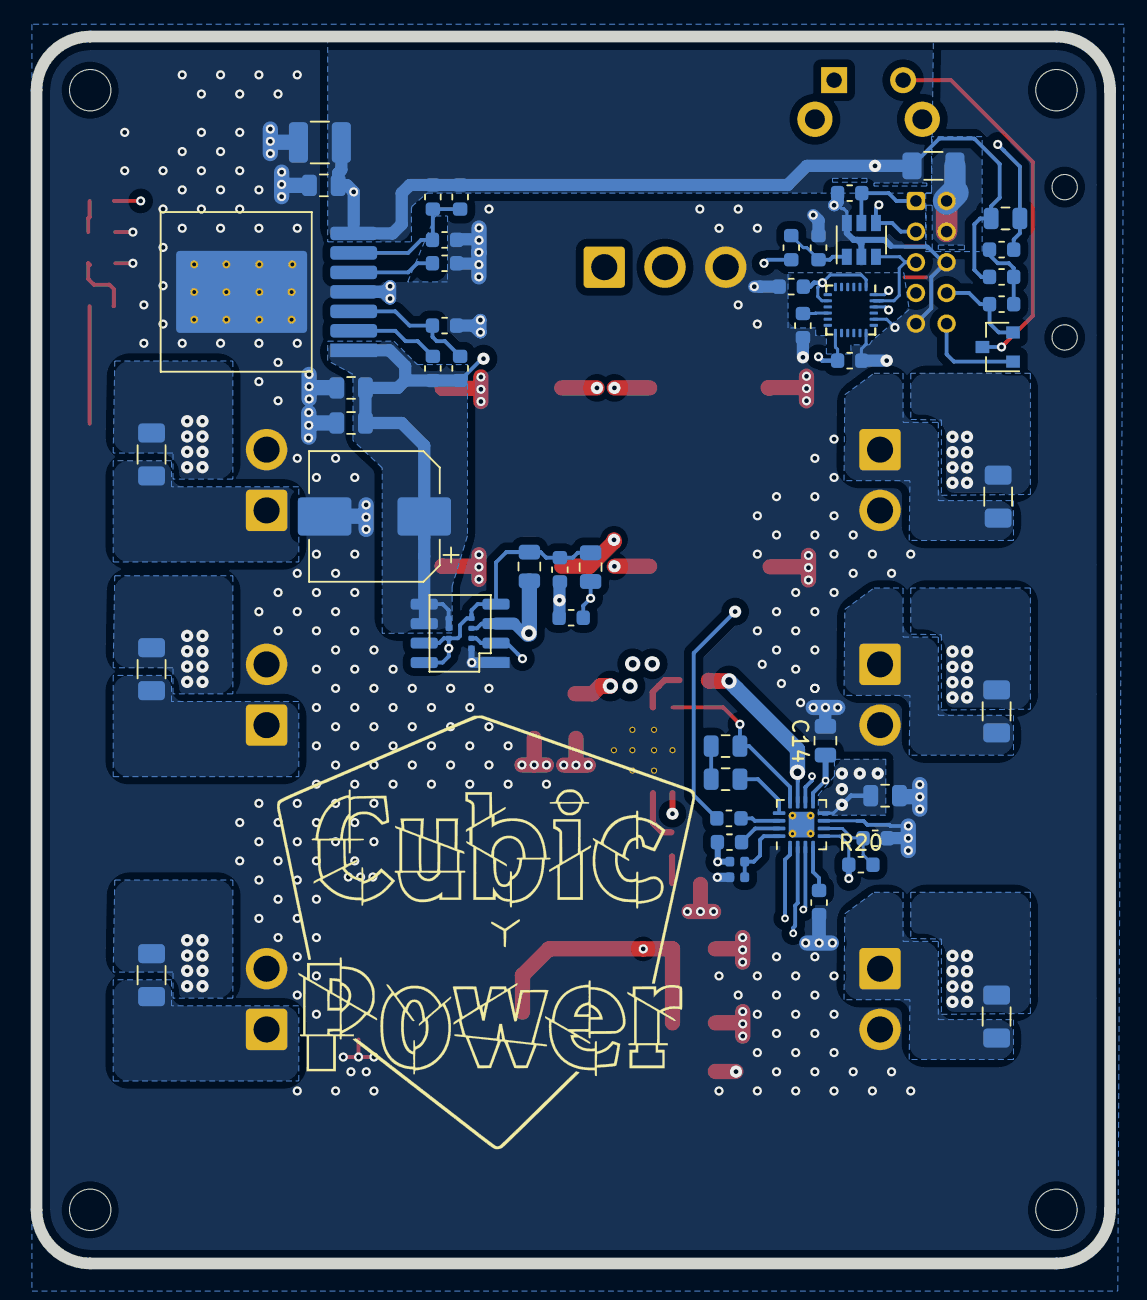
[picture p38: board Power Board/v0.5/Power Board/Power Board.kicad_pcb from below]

Board: 4 copper layers, 70.0 x 80.0 mm, 89 parts (50 on the bottom side), 50 nets.

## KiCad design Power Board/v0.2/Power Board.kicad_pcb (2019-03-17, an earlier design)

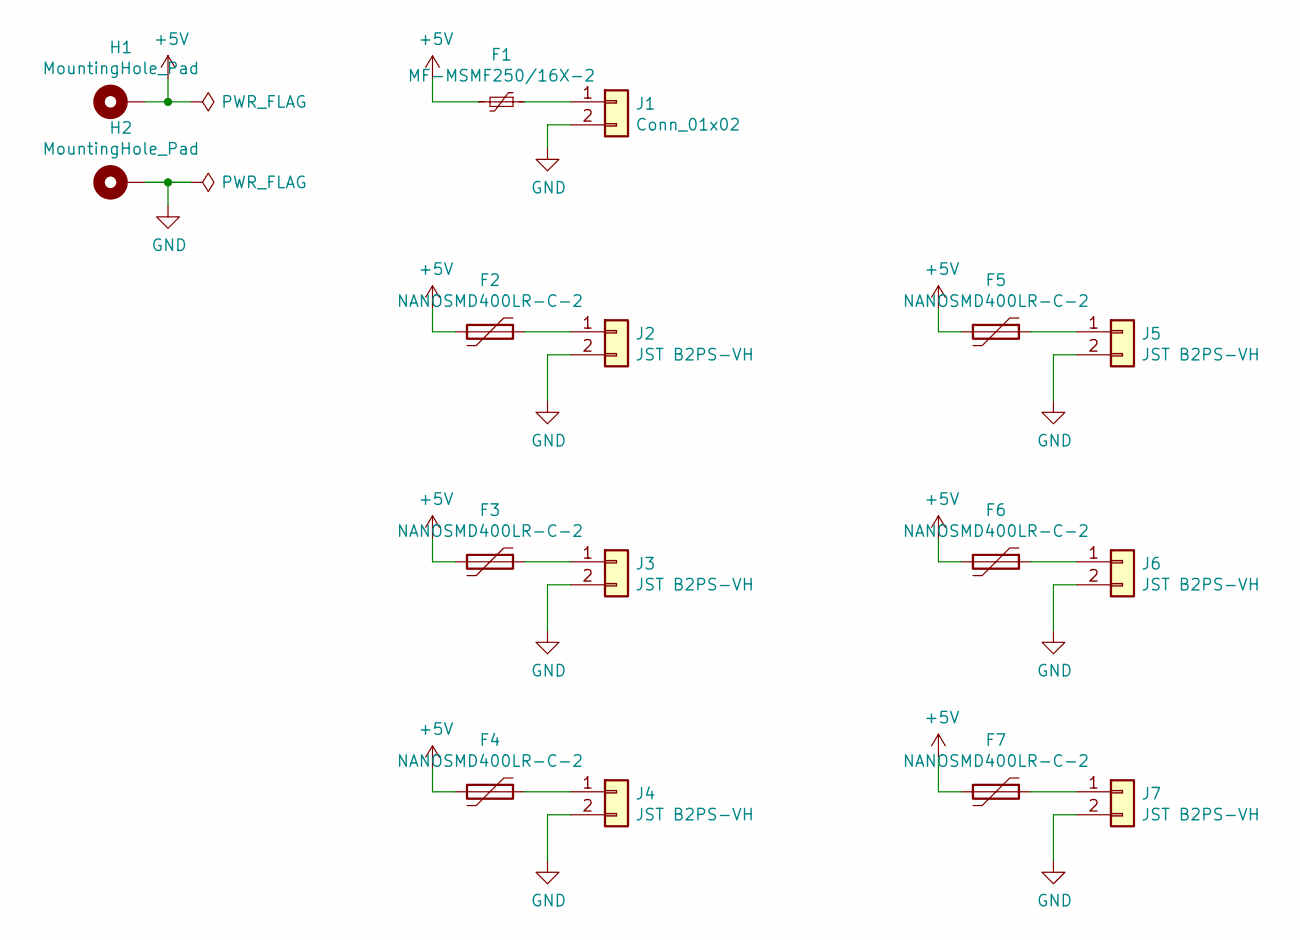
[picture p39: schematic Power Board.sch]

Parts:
F1: MF-MSMF250/16X-2; Bourns MF-MSMF Style 2
F2, F3, F4, F5, F6, F7: NANOSMD400LR-C-2; Fuse_1206_3216Metric
H1, H2: MountingHole_Pad; MountingHole_3mm_Pad
J1: Conn_01x02; PinSocket_1x02_P2.54mm_Horizontal
J2, J3, J4, J5, J6, J7: JST B2PS-VH; JST_VH_B2PS-VH_1x02_P3.96mm_Horizontal

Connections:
+5V: F1.2, F2.2, F3.2, F4.2, F5.2, F6.2, F7.2, H1.1
GND: H2.1, J1.2, J2.2, J3.2, J4.2, J5.2, J6.2, J7.2
unnamed: F1.1, J1.1
unnamed: F2.1, J2.1
unnamed: F3.1, J3.1
unnamed: F4.1, J4.1
unnamed: F5.1, J5.1
unnamed: F6.1, J6.1
unnamed: F7.1, J7.1

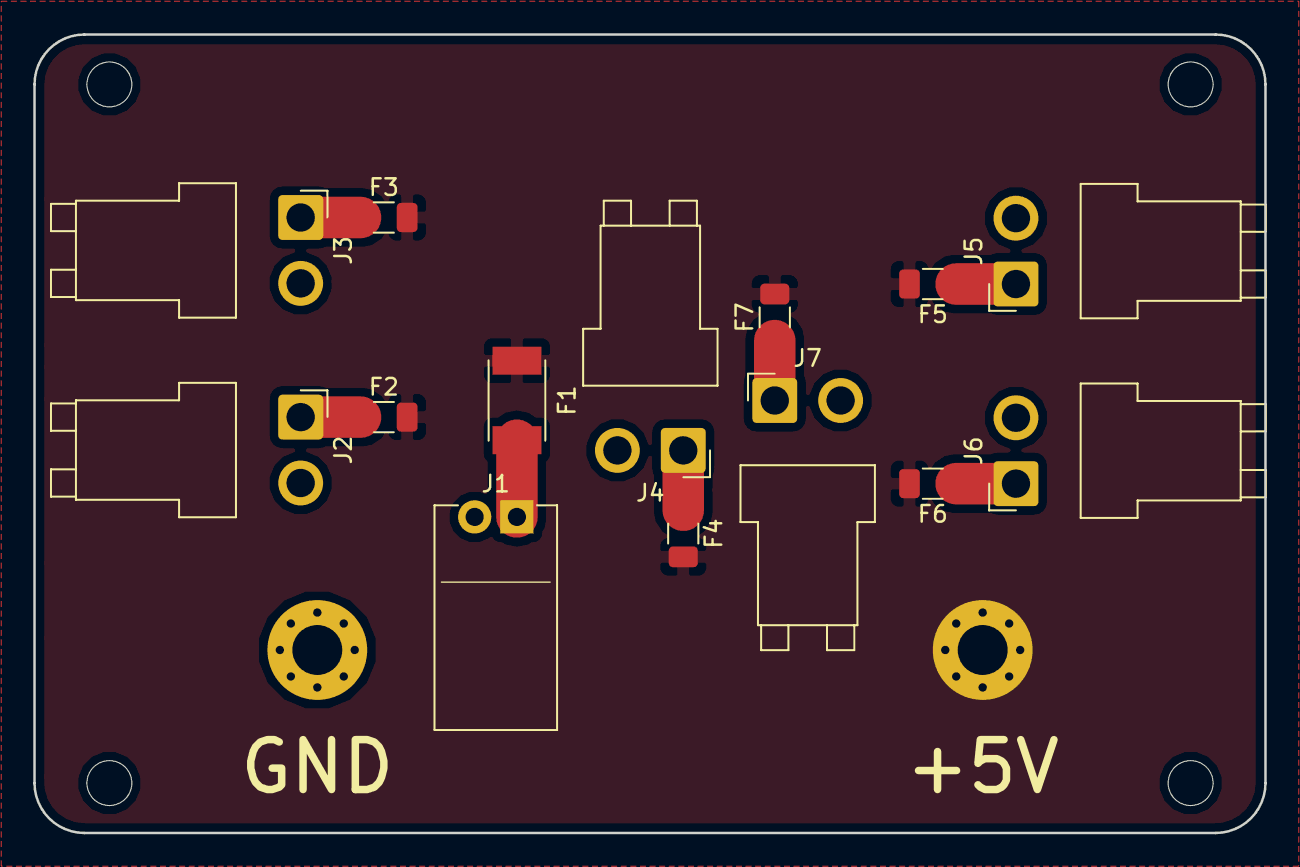
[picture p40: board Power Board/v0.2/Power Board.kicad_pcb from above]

Board: 2 copper layers, 74.0 x 48.0 mm, 16 parts (0 on the bottom side), 9 nets.

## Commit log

2019-02-17 Power distribution board v0.1
    [Power Board.kicad_pcb, Power Board.sch]
2019-03-17 power board v0.2. Smaller fuses, smaller board.
    [Power Board.kicad_pcb, Power Board.sch]
2019-03-20 Work in progress on v0.3 of power board.
    [Panel_Power.sch, Pi_Power.sch, Power Board.kicad_pcb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]
2019-03-22 power board v0.3 - Raspberry Pi side only
    [Pi_Power.sch, Power Board BOM.csv, Power Board.sch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]
2019-03-26 Oops, a no-connect was misaligned.
    [Power Board.sch]
2019-03-26 Revised soft power switch. Now switches power to 5V regulator.
    [Panel_Power.sch, Pi_Power.sch, Power Board BOM.csv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]
2019-03-27 Remove Pi_Power.sch
    [Pi_Power.sch]
2019-03-28 Create the LED panel supply circuit.
    [Panel_Power.sch, Pi_Power.sch, Power Board BOM.csv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]
2019-04-02 Update components with available parts.
    [Panel_Power.sch, Pi_Power.sch, Power Board BOM.csv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]
2019-04-02 Document Raspberry Pi P1 connector wiring.
2019-04-03 Draw all custom footprints and assign to components.
    [Panel_Power.sch, Pi_Power.sch, Power Board.sch]
2019-04-04 Work in progress.
    [Panel_Power.sch, Pi_Power.sch, Power Board.kicad_pcb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]
2019-04-06 L8 footprint is Coilcraft XAL1580, not some Kemet cap.
    [Panel_Power.sch, Power Board.kicad_pcb]
2019-04-07 Start Power Board v0.4 by copying v0.3.
    [Panel_Power.sch, Pi_Power.sch, Power Board.kicad_pcb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]
2019-04-07 Update schematic with panel power Cin, Cout.
    [Power Board BOM.csv]
2019-04-07 Update panel power with Cin, Cout.
    [Panel_Power.sch, Power Board.sch]
2019-04-09 New 4 Layer Layout
    Needed 4 layers and double sided design in order to make everything fit
    [Power Board.kicad_pcb]
2019-04-11 Preliminary Layout Started
    Have most of the components moved to reasonable locations.
    Initial layout placeholders to get a general sense of connections.
    Added a sheet with the MPU-9250 Circuit but not pushed to board yet.
    Still need to add a lot of copper pours and stitching.
    [MPU9250.sch, Panel_Power.sch, Pi_Power.sch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]
2019-04-12 More Layout Work
    Just another preliminary update so we can both work on changes
    [Power Board.kicad_pcb]
2019-04-14 Updated board dimensions and mt. holes, tweaked MPU schematic.
    [MPU9250.sch, Power Board.kicad_pcb, Power Board.sch]
2019-04-14 Change keep-out text.
    [Power Board.kicad_pcb]
2019-04-15 Widen board to 70mm, delineate mechanical keepout zones.
    [MPU9250.sch, Power Board.kicad_pcb, Power Board.sch]
2019-04-15 Revert "Change keep-out text."
    This reverts commit ca402f97387596ad30b5b3e9a838d0bd200cb8e0.
    [Power Board.kicad_pcb]
2019-04-15 Revert "Updated board dimensions and mt. holes, tweaked MPU schematic."
    This reverts commit 6936a160ef8a0f8efd2e8f2d18775030a6ae8800.
    [MPU9250.sch, Power Board.kicad_pcb, Power Board.sch]
2019-04-16 Add ADC to monitor battery voltage.
    [MPU9250.sch, Panel_Power.sch, Pi_Power.sch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]
2019-04-18 Almost Rough Draft Done
    Mostly routed but needs lots of TLC. Need to check rule definitions before DRC
    [Power Board.kicad_pcb, Power Board.sch, Power_Meter.sch]
2019-04-19 More routing and zone placements. Needs more TLC Needs DRC review and fix
    [Power Board.kicad_pcb, Power Board.sch]
2019-04-20 Better ground flow through Q1 Need to add more copper for panel connector between fuse and ferrite
    [Power Board.kicad_pcb]
2019-04-20 Changed connections to panel connectors. Did some of the TLC work on the pours. Still need to fix DRC, mostly for U2 clearance issues that aren't really a DRC
    [Power Board.kicad_pcb]
2019-04-21 Tracks and rules tweaked to eliminate most DRC 2 DRC errors remain which don't seem valid
    [Power Board.kicad_pcb]
2019-04-22 Final Cleanup 2 DRC Errors that seem false Silkscreen needs work
    [Panel_Power.sch, Power Board.kicad_pcb]
2019-04-23 Rework routing to panel connectors. WIP.
    [Panel_Power.sch, Power Board.kicad_pcb, Power Board.sch]
2019-04-23 Reattach LED to Panel_Power.
    [Power Board.kicad_pcb]
2019-04-25 Modified zones on the left side of the board
    [Power Board.kicad_pcb]
2019-04-26 Notes on Raspberry Pi Linux configuration
2019-04-26 More Zones Changes/Improvements
    [Power Board.kicad_pcb]
2019-04-27 Final Layout
    Just need silk screen cleanup
    [Power Board.kicad_pcb]
2019-04-28 Add 3D models for some components.
    [Coilcraft-XAL1580-102.step, JST-B2PS-VH.step, JST-B3PS-VH.step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]
2019-04-28 Add 3D models for more components.
    [DQY8_3P2X4P3 v1.step, DQY8_3P2X4P3.step, LittelFuse_nanoSMD400LR-C.step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]
2019-04-28 Clean up silkscreen, add logo artwork.
    [Power Board.kicad_pcb]
2019-04-30 Change In1.Cu ground pour to use solid connections to through holes.
    [Power Board.kicad_pcb]
2019-04-30 Update BOM. Change R20 to 0603 package.
    [MPU9250.sch, Panel_Power.sch, Pi_Power.sch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]
2019-05-02 Add BOM massage script. Add generated files: schematic PDF, BOM CSVs, Gerbers, drill file.
    [Digikey Order.csv, Pi_Power.sch, Power Board BOM.csv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]
2019-05-28 Create power board v0.5.
    [Coilcraft-XAL1580-102.step, DQY8_3P2X4P3 v1.step, DQY8_3P2X4P3.step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]
2019-05-28 Update version number on silkscreen.
    [Power Board.kicad_pcb]
2019-05-28 Set solder mask minimum width to zero.
    [Power Board.kicad_pcb]
2019-06-01 Document the wiring.
2019-06-01 Document Pi-to-Power wire length.
2019-06-11 Correct Coilcraft XAL1580 footprint: enlarge pads, break up paste areas.
    [Power Board.kicad_pcb]
2019-06-11 Correct C14 footprint, remove C6 and C9 incorrect package.
    [Panel_Power.sch, Pi_Power.sch, Power Board.kicad_pcb]
2019-06-11 Create generated files: Schematic, BOM, Digikey, iBOM, Gerber, Excellon.
    [Digikey Order.csv, Power Board BOM.csv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]
2019-09-01 update README, include Fusion 360 files.
    [Cube Stand Interlock v1.f3d, Pi Connector Cover 4 v4.f3d, Static Stand Travel Case 2 v9.f3z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]
2019-09-01 add STL files.
    [Battery Carrier v64.stl, Bottom Shelf v54.stl, Frame v35.stl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]
2019-09-22 LED panels are now available from 1BitSquared.
